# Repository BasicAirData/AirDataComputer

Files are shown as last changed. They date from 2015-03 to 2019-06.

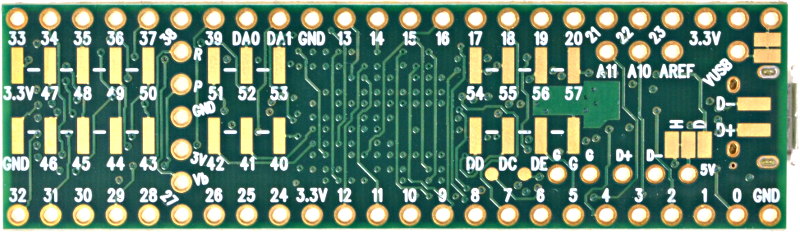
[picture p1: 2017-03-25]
Hardware/3D support/teensy3.6/images/teensy36 Back.jpg

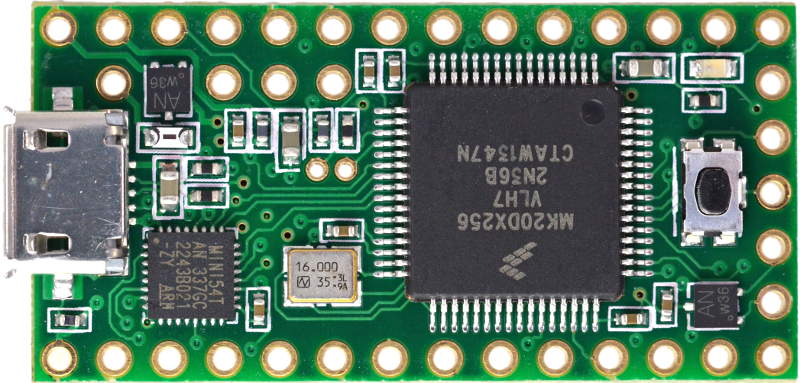
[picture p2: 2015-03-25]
Hardware/3D support/teensy3.1/images/teensy31front.jpg

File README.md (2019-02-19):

[Brainstorming in progress. New design. Rookies welcome](https://www.basicairdata.eu/projects/air-data-systems/brainstorming-air-data-system-winter-2018-2019/)

[Airborne ADC Video](http://www.basicairdata.eu/projects/skyeye/review-diy-air-data-computer-asgard-and-pitot-static-on-skyeye-rc-model/)
# [Air Data Computer](https://github.com/BasicAirData/AirDataComputer/wiki)
Asgard ADC

## Description
An air data computer (ADC) is an essential avionics component found in modern aircraft. This unit can determine True Airspeed, Mach number, Altitude, and common air properties from a pitot-static probe data and an outside air temperature probe.

This repository, together with the media published on the BasicAirData website, contains the information to build from scratch a recreational grade DIY Air Data Computer. This device can transmit data via USB serial port and Bluetooth, and log all data on a MicroSD.

The project is a work in progress

This Air Data Computer can be controlled sending plain text [messages](https://github.com/BasicAirData/AirDataComputer/tree/master/Software/Documentation/ADC%20Common%20Message%20Set) from any serial / bluetooth terminal.<br>
We are developing [Air Data Bridge](https://github.com/BasicAirData/AirDataBridge), a simple app for Android devices to connect via Bluetooth and use this ADC on-the-field in an easy way.

## At a Glance
* [Fast Assembly](https://www.basicairdata.eu/projects/airdatacomputer/asgard-adc/assembly-adc-asgard/)
* [Pictures](http://www.basicairdata.eu/projects/airdatacomputer/asgard-adc/adc-asgard-pictures/)
* [Typical applications](http://www.basicairdata.eu/projects/air-data-systems/air-data-systems-applications/)

## Reference documents

[Notes on firmware programming](https://www.basicairdata.eu/projects/notes-on-firmware-programming/)

[Basic Air Data Home Page](https://www.basicairdata.eu)

[Code of conduct](CODE_OF_CONDUCT.md)

[Contributing Information](CONTRIBUTING.md)

[Repository License](LICENSE)

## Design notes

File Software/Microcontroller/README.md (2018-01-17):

## Status
[Work in progress, refer to the Wiki](https://github.com/BasicAirData/AirDataComputer/wiki)

## Introduction
Within "Hardware Integration Test" folder you find a sketch for test the hardware of a Asgard ADC.
Firmware folder will contain the sketch that need to ve uploaded to ADC. The firmware supports Bluetooth and SD card.
Libraries folder contains the libraries you need to place in your Arduino IDE library folder to be able to compile the ADC sketch.

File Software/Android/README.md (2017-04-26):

## Asgard
Android Application to interface with the ADC

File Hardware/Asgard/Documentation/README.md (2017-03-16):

# Hardware Folder

In "Amaranthi2" folder you find all the Amaranth i2 ADC related material
* Enclosure	
* Kicad Amaranth i2	Printed Circuit Board
* Pinout	
* Schematic

In "3D support" folder you find free 3D models of the Teensy board 3.1/3.2 and the SD card holder used for the virtual assembly of Amaranth i2 ADC

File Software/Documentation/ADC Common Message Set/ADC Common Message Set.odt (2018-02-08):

BasicAirData – Air Data Computer

Communication Protocol - Common Message Set

Attention, this is a work in progress version

Draft Version 0.5 – 6th Feb 2018

Draft Version 0.4 – 6th Jan 2018

Draft Version 0.3 – 11th May 2017

Draft Version 0.2 – 26th Apr 2017

Draft Version 0.1 – 4th Jan 2017

Legend for the table colors:

- Green = implemented

- Red = not implemented

- Blue = work in progress

ID | Field | Field Name | Description
0 | HBQ | HEARTBEAT_REQ | Check if the system is present and responding
1 | HBA | HEARTBEAT_ASSERT | Answer about the system presence
2 | TMS | TIME_SET | Set date and time of the ADC
3 | TMQ | TIME_REQ | Ask for date and time
4 | TMA | TIME_ASSERT | The Date and time
5 | STS | STATUS_SET | Set the status
6 | STQ | STATUS_REQ | Ask for ADC configuration status
7 | STA | STATUS_ASSERT | The Status
8 | DTS | DATA_SET | Set the data
9 | DTQ | DATA_REQ | Ask for the ADC data
10 | DTA | DATA_ASSERT | The data
11 | LCS | LOG_CURRENTFILE_SET | Set the current log file name
12 | LCQ | LOG_CURRENTFILE_REQ | Ask for the current log file name
13 | LCA | LOG_CURRENTFILE_ASSERT | The current log file
14 | DFS | DATA_FREQ_SET | Set the ADC to send Data at specified frequencies
15 | DFQ | DATA_FREQ_REQ | Ask for the ADC Data Frequencies
16 | DFA | DATA_FREQ_ASSERT | The Data Frequencies
17 | FMQ | FILE_MANAGER_REQ | Manage SD Files
18 | FMA | FILE_MANAGER_ASSERT | File manager answers
19 | CCS | CALIBRATION_CON_SET | Setup Sensor Calibration
20 | CCA | CALIBRATION_CON_ASSERT | General calibration ack and parameter from ADC

Every message string will begin with a “$” character and will end with a “\n” (newline).

# 0 – HBQ – HEARTBEAT_REQ

The heartbeat message ask if a system is present and responding.

The remote system will respond with a HEARTBEAT_ASSERT (#1).

0 | Field String | $HBQ
1 | description | The description of the requesting device
2 | firmware_version | The version of the communication protocol

Example:

$HBQ,StatusVisualizer,1

# 1 – HBA – HEARTBEAT_ASSERT

The heartbeat message answer if a system is present and responding.

This message is typically the answer of a HEARTBEAT_REQ (#0).

0 | Field String | $HBA
1 | description | The description of the responding device
2 | firmware_version | The version of the communication protocol

Example:

$HBA,ASGARD,0.5

# 2 – TMS – TIME_SET

The request to set the remote datetime.

The remote system will respond with a TIME_ASSERT (#4).

0 | Field String | $TMS
1 | Time as seconds since Jan 1, 1970 | Long Integer, seconds

Example:

$TMS,1493151334

# 3 – TMQ – TIME_REQ

Ask for the remote datetime.

The remote system will respond with a TIME_ASSERT (#4).

0 | Field String | $TMQ

Example:

$TMQ

# 4 – TMA – TIME_ASSERT

The message contains the current datetime of the device.

0 | Field String | $TMA
1 | Time as seconds since Jan 1, 1970 | Long Integer, seconds

Example:

$TMA,1493151334

# 5 – STS – STATUS_SET

The request to set the status of the remote device.

It is possible to set some parameters and leave untouched some others, using the value “-1”.

The remote system will respond with a STATUS_ASSERT (#7).

0 | Field String | $STS
1 | SD card present | 1 Present. 0 Not present. E=error code
2 | Deltap sensor | 1 Present. 0 Not present. E=error code
3 | Absolute pressure sensor | 1 Present. 0 Not present. E=error code
4 | External Temperaure sensor | 1 Present. 0 Not present. E=error code
5 | Deltap sensor temperature | 1 Present. 0 Not present. E=error code
6 | Absolute pressure sensor temperature | 1 Present. 0 Not present. E=error code
7 | Real time clock battery | 1 Present. 0 Not present.
8 | Error/Warning | That should be a code handled directly by firmware. Exception handling is not implemented. “SDLOW” This is a warning
9 | BT Present | 1 Present. 0 Not present. E=error code (BT module hooked to Serial1)

Example:

$STS,1,1,-1,1,1,1,1,N,1

# 6 – STQ – STATUS_REQ

Ask for the remote status.

The remote system will respond with a STATUS_ASSERT (#7).

0 | Field String | $STQ

Example:

$STQ

# 7 – STA – STATUS_ASSERT

The message contains the current status of the device.

0 | Field String | $STA
1 | SD card present | 1 Present. 0 Not present. E=error code. N not set.
2 | Deltap sensor | 1 Present. 0 Not present. E=error code. N not set.
3 | Absolute pressure sensor | 1 Present. 0 Not present. E=error code. N not set.
4 | External Temperaure sensor | 1 Present. 0 Not present. E=error code. N not set.
5 | Deltap sensor temperature | 1 Present. 0 Not present. E=error code. N not set.
6 | Absolute pressure sensor temperature | 1 Present. 0 Not present. E=error code
7 | Real time clock battery | 1 Present. 0 Not present.
8 | Error/Warning | That should be a code handled directly by firmware. Exception handling is not implemented. “SDLOW” This is a warning
9 | BT Present | 1 Present. 0 Not present. E=error code (BT module hooked to Serial1)

Example:

$STA,1,1,1,1,1,1,1,,0

All the sensors, SD card, real time clock battery are present and operational, no errors are reported.

$STA,1,1,0,1,1,1,0,SDLOW,1

All the sensors except external temperature, and SD card are present. SD card space shortage is reported.

# 8 – DTS – DATA_SET

The request to set (force) the data of the remote device.

It is possible to set some parameters and leave untouched some others, using the value “-1”.

The remote system will respond with a DATA_ASSERT (#10). [Note. How to decide what #10 message should include? The reply #10 will contain no data at all “$DTA”. It’ a simple acknowledge]

i | Field String | $DTA
1 | Timestamp see msg #4 | Time as seconds since Jan 1, 1970
2 | Deltap [Sensor units, counts] | integer. Sensor dependent.
3 | Absolute Pressure [Sensor units, counts] | integer. Sensor dependent
4 | Ext Temperature [Sensor units, counts] | integer. Sensor dependent
5 | Temp deltap [Sensor units, counts] | integer. Sensor dependent
6 | Temp absolute [Sensor units, counts] | integer. Sensor dependent
7 | Deltap [Pa] | float
8 | Absolute Pressure [Pa] | float
9 | Ext Temperature [K] | float
10 | Temp deltap [K] | float
11 | Temp absolute [K] | float
12 | IAS [m/s] | float
13 | TAS [m/s] | float
14 | Altitude [m] | float
15 | OAT [K] | float
16 | Relative time micro millis [s*10^-6] | integer
17 | Uncertainty IAS [m/s] | float
18 | Uncertainty TAS [m/s] | float
19 | Uncertainty Altitude [m] | float
20 | Uncertainty OAT [K] | float
21 | Air Density [kg/m^3] | float
22 | Air Viscosity [Pa*s] | float
23 | Re | float
24 | c factor | float

Example:

Set the value of ext temperature

$DTS,,,,,,,,,350,,,,,,,,,,,,,,,

# 9 – DTQ – DATA_REQ

Ask for the remote data. Selects the required data with the fields value. If a 0 is sent at the position i then the ADC will send a #10 reply with the field i not valued. If a 1 is sent at the position i then the ADC will send a #10 reply with the field i valued.

Configuration data will be saved to the SD card (CONFIG.CFG file),

Use the “$DTQ” command, without parameters, and the remote system will respond with a DATA_ASSERT (#10) instead.

i | Field String | $DTQ
1-24 | Select | 0 if data field not required. 1 if data field required

Example:

Request all the data fields of #10

$DTQ,1,1,1,1,1,1,1,1,1,1,1,1,1,1,1,1,1,1,1,1,1,1,1,1

Request all the data fields except Deltap and Ext Temperature

$DTQ,1,0,1,0,1,1,1,1,1,1,1,1,1,1,1,1,1,1,1,1,1,1,1,1

Request time, deltap, p, ext temperature

$DTQ,1,0,0,0,0,0,1,1,1,0,0,0,0,0,0,0,0,0,0,0,0,0,0,0

Simply request a string of data

$DTQ

# 10 – DTA – DATA_ASSERT

Data lengths shown in the table below are variable and conservative. The ADC will respond to a #9 message with a DTA – DATA_ASSERT that contains only the data fields that have been marked with 1 within the #9 message.

i | Field String | $DTA
1 | Timestamp see msg #4 | Time as seconds since Jan 1, 1970
2 | Deltap [Sensor units, counts] | 6 Chars, integer. Sensor dependent.
3 | Absolute Pressure [Sensor units, counts] | 6 Chars, integer. Sensor dependent
4 | Ext Temperature [Sensor units, counts] | 5 Chars, integer. Sensor dependent
5 | Temp deltap [Sensor units, counts] | 5 Chars, integer. Sensor dependent
6 | Temp absolute [Sensor units, counts] | 5 Chars, integer. Sensor dependent
7 | Deltap [Pa] | 8 Chars, 2 decimal digit
8 | Absolute Pressure [Pa] | 8 Chars, 1 decimal digit
9 | Ext Temperature [K] | 5 Chars, 1 decimal digit
10 | Temp deltap [K] | 5 Chars, 1 decimal digit
11 | Temp absolute [K] | 5 Chars, 1 decimal digit
12 | IAS [m/s] | 6 Chars, 2 decimal digit
13 | TAS [m/s] | 6 Chars, 2 decimal digit
14 | Altitude [m] | 7 Chars, 2 decimal digit
15 | OAT [K] | 5 Chars, 1 decimal digit
16 | Relative time micro millis [s*10^-6] | 5 Chars, integer
17 | Uncertainty IAS [m/s] | 3 Chars, 1 decimal digit
18 | Uncertainty TAS [m/s] | 3 Chars, 1 decimal digit
19 | Uncertainty Altitude [m] | 3 Chars, 1 decimal digit
20 | Uncertainty OAT [K] | 3 Chars, 1 decimal digit
21 | Air Density [kg/m^3] | 8 Chars, 6 decimal digit
22 | Air Viscosity [Pa*s] | 10 Chars, 8 decimal digit
23 | Re | 8 Chars, 1 decimal digit
24 | c factor | 6 Chars, 4 decimal digit

Example:

$DTA,1493151334,6608,******,******,*****,*****,*****,472.60,100926.1,15.0,18.3,18.6,27.77,27.77,63.1,15.0,1244,0.4,0.7,1.1,0.3,1.225000,18.396057,15081.1,0.9977

# 11 – LCS – LOG_CURRENTFILE_SET

This message request to set the current active log file name. Reply is #13 msg.

If the file doesn’t exist, a new file is created.

0 | Field String | $LCS
1 | Name | The requested log file name. Use the “?” character to create a new one using a progressive number

Example: (set the file to DATALOG.CSV)

$LCS,DATALOG.CSV

Example: (set the file to a new file. a progressive name, starting from LOG_0000.CSV, will be assigned)

$LCS,LOG_?.CSV

# 12 – LCQ – LOG_CURRENTFILE_REQ

Ask for the log file name. Reply is the active file name message #13

0 | Field String | $LCQ

Example:

$LCQ

# 13 – LCA – LOG_CURRENTFILE_ASSERT

The message contains the current active log file.

0 | Field String | $LCA
1 | frequency | The current active log file name

Example:

$LCA,DATALOG.CSV

# 14 – DFS – DATA_FREQ_SET

The request to set the frequency rate of the remote data messages.

It is possible to set some parameters and leave untouched some others, using the value “-1”.

The remote system will respond with a DATA_FREQ_ASSERT (#16).

0 | Field String | $DFS
1 | COM frequency | The requested frequency rate (messages per second) to Serial interface
2 | BT frequency | The requested frequency rate (messages per second) to Bluetooth
3 | SD frequency | The requested frequency rate (messages per second) to SD Card

Example: (set the serial frequency to 10 Hz, Bluetooth frequency to 0.5 Hz, and SD frequency to 30 Hz)

$DFS,10,0.5,30

Example: (set the Bluetooth frequency to 2 Hz. SD and Serial frequency won’t be changed)

$DFS,-1,2,-1

# 15 – DFQ – DATA_FREQ_REQ

Query the frequency rate of the remote data messages.

The remote system will respond with a DATA_FREQ_ASSERT (#16).

0 | Field String | $DFQ

Example:

$DFQ

# 16 – DFA – DATA_FREQ_ASSERT

The message contains the current frequency rate of the data messages.

0 | Field String | $DFA
1 | COM frequency | The current frequency rate (messages per second) to Serial
2 | BT frequency | The current frequency rate (messages per second) to Bluetooth
3 | SD frequency | The current frequency rate (messages per second) to SD Card

Example: (A serial frequency of 10 Hz, Bluetooth frequency of 1 Hz, and SD frequency of 30 Hz)

$DFA,10,1,30

# 17 – FMQ – FILE_MANAGER_REQ

Manage Log Files on SD card.

0 | Field String | $FMQ
1 | Command | LST = FILE_LIST NEW = NEW_FILE DEL = DELETE_FILE PRP = FILE_PROPERTIES DMP = FILE_DUMP
2 | Operation parameter | Filename, if file list is selected is left void

Example: (Get the list of file currently on the SD root directory)

FMQ,LST

Example: (Creates the file LOG1.CSV)

FMQ,NEW,LOG1.CSV

Example: (Deletes the file LOG1.CSV)

FMQ,DEL,LOG1.CSV

Example: (Gets LOG1.CSV file properties)

FMQ,PRP,LOG1.CSV

Example: (Dumps PAGNOTTA.CSV file content)

FMQ,DMP,PAGNOTTA.CSV

# 18 – FMA – FILE_MANAGER_ASSERT

Data from SD files. Payload depends on #17 FMQ Message

In reply to msg #17 FILE_LIST = LST

Number of total parameters equal to 3n+2, n is the number of files present on the SD card.

0 | Field String | $FMA
1 | Command | LST
2 | Number of files | Integer, the number of transmitted files
3 | Field2 | Filename #1
4 | Field3 | Size file #1
5 | Field4 | Timestamp #1; Time as seconds since Jan 1, 1970 (Long Integer)
6 | Field5 | Filename #2
7 | Field6 | Size file #2
… | … | …
3n+2 | Field(3n+2) | Timestamp #n; Time as seconds since Jan 1, 1970 (Long Integer)

Example: (The root directory contains 3 files)

$LFA,LST,3,DATALOG.CSV,1560,1517256700,LOG1.CSV,0,1517251200,PAGNOTTA.CSV,68203,1517256745

In reply to msg #17 NEW_FILE = NEW

Acknowledge the creation of a new file. The new file is set as current ADC log file.

0 | Field String | $FMA
1 | Command | NEW
2 | File name | The name of the newly created file Use the “?” character to create a new one using a progressive number

Example:

$FMA,NEW,PAGNOTTA.CSV (PAGNOTTA.CSV created)

Example:

$FMA,NEW,LOG_?.CSV (if LOG_0000.CSV exists, LOG_0001.CSV created)

In reply to msg #17 DEL_FILE = DEL

Acknowledge the deletion of specified file.

0 | Field String | $FMA
1 | Command | DEL
2 | File name | The name of the file

Example:

$FMA,DEL,PAGNOTTA.CSV (PAGNOTTA.CSV deleted)

$FMA,DEL (No files deleted)

In reply to msg #17 FILE_PROPERTIES = PRP

Returns the name and the dimension of the specified file.

0 | Field String | $LFA
1 | Command | PRP
2 | Name | The name of the file
3 | Size | Size in bytes of specified file
4 | Timestamp | Time as seconds since Jan 1, 1970 (Long Integer)

Example:

$FMA,PRP,PAGNOTTA.CSV,15600,1517256700 (returns PAGNOTTA.CSV properties)

$FMA,PRP (returns nothing)

In reply to msg #17 FILE_DUMP = DMP

Returns the log file contents line by line.

Another message received by the same serial interface will stop the dump truncating the file

Message is always ended with a special $EOF sequence.

In order, it returns:

1) The $FMA string:

0 | Field String | $FMA
1 | Command | DMP
2 | Name | The name of the file

2) The file content:

First line

Second line

…. (Send another message to stop this phase and truncate the file)

Last line

3) The End of File acknowledgment

$EOF

Example: (it dumps PAGNOTTA.CSV file)

$FMA,DMP,PAGNOTTA.CSV

$DTA,first_line

$DTA,last_line

$EOF

# 19 –CCS–CALIBRATION_CON_SET

Manages calibration parameter of sensors.

General command message structure

0 | Field String | $CCS
1 | Command | EXE – Order to perform a calibration on the specified sensor and with the mode specified USE – Applies the specified calibration parameters to the sensor SEN – Send out the calibration data for the specified sensor
2 | Sensor_ID_number | The ID number of the sensorr
3 | Mode | 1 – Offset Only 2 - Linear
4 | Parameter 1 | Command dependent
5 | Parameter 2 | Command dependent

EXE – Command description

After a EXE command is issued the ADC performs the required calibration routine on the sensors and update the required sensor information. After the procedure is complete the ADC sent out a message #20 CCQ.

0 | Field String | $CCS
1 | Command | EXE
2 | Sensor_ID_number | The ID number of the sensor. Integer, 2 Bytes
3 | Mode | 1 – Offset Only, calibrate the indicated sensor zero offset 2 – Linear, calibrate the indicated sensor zero offset and gain

EXAMPLE:

$CCS,EXE,1,1

Once finished sent out a message #20 containing the offset parameter used

USE – Command description

The ADC uses the specified calibration information and reply with a #20 message.

0 | Field String | $CCS
1 | Command | USE
2 | Sensor_ID_number | The ID number of the sensor. Integer, 2 Bytes
3 | Mode | 1 – Offset Only, calibrate the indicated sensor zero offset 2 – Linear, calibrate the indicated sensor zero offset and gain
4 | Parameter 1 | Offset if Mode==1
5 | Parameter 2 | Gain if Mode==2

EXAMPLE:

$CCS,USE,2,1,45,,

The ADC sets the sensor 2 offset to 45, then send out a #20 message $CGQ,2,45,,

SEN – Command description

Send out the calibration data for the specified sensor. Returns calibration offset and gain

0 | Field String | $CCS
1 | Command | SEN
2 | Sensor_ID_number | The ID number of the sensorr

Example:

$CCS,SEN,1

Reply

$CCA,1,1234,0.995955

HWD– Command description

The ADC uses the specified sensor hardware information and reply with a #20 message that contains all the data fields.

0 | Field String | $CCS
1 | Command | HWD
2 | Deltap Sensor Min Count value | Minimum number of counts read by the deltap sensor
3 | Absolute pressure sensor Min Count value | Minimum number of counts read by the abs pressure sensor
4 | Deltap Sensor Max Count value | Maximum number of counts read by the deltap sensor
5 | Absolute pressure sensor Max Count value | Maximum number of counts read by the abs pressure sensor
6 | Deltap Sensor Min Pressure | Minimum pressure deltap sensor. Pascal
7 | Abs Sensor Min Pressure | Minimum pressure abs sensor. Pascal
8 | Deltap Sensor Max Pressure | Maximum pressure deltap sensor. Pascal
9 | Abs Sensor Max Pressure | Maximum pressure abs sensor. Pascal

# 20 –CALIBRATION_CON_ASSERT

Reply to message #19, EXE Command

Reply to #19 message . Command EXE mode 1. The reply will be the same of that required to a message #19, Command SEN mode 1 or Message #19, Command USE mode 1

0 | Field String | $CCA
1 | Sensor_ID_number | The ID number of the sensor. Integer, 2 Bytes
2 | Parameter 1 | Offset value. Integer, 6 bytes

EXAMPLE:

In reply to #19 $CCS,EXE,1,1

$CCA,1,25

The #20 reply contents the used offset value 25 for the sensor 1

Reply to message #19, USE Command

Reply to #19 message . Command USE mode 2, Command SEN mode 2

0 | Field String | $CCA
1 | Sensor_ID_number | The ID number of the sensor. Integer, 2 Bytes
2 | Parameter 1 | Offset value. Integer, 6 bytes
3 | Parameter 2 | Gain

EXAMPLE:

In reply to #19 $CCS,USE,1,2

$CCA,1,25.0.99995

The #20 reply contents the used offset value 25 and the gain 0,99995 for the sensor 1

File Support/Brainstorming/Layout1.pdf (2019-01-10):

Analog pressure
sensors
5V
6 Channels

Integrated data acquisition System

Nos. 3 to 5 ELVR Dp
1” (https://eu.mouser.com/ProductDetail/Amphenol-All-Sensors/ELVR-L01D-F1RT-I-NA5F) and 10” (https://eu.mouser.com/ProductDetail/Amphenol-All-Sensors/ELVR-L10D-F1RT-I-NA5F) in H2O range
pressure sensors
N.1
BARO-A-4V-MINI-PRIME (https://eu.mouser.com/ProductDetail/All-Sensors/BARO-A-4V-MINI-PRIME?qs=ILks%2FQglqVSxsY2LQVPGvQ%3D%3D)

Nos. 1
ADAS3022BSTZ : 16-Bit, 1
MSPS, 8-Channels (https://eu.mouser.com/ProductDetail/Analog-Devices/ADAS3022BSTZ)
SPI
BUS

Host Microcontroller board Teensy 3.6

Proposal, components to be used for the new unit

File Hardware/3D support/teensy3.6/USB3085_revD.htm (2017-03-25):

Rapporto di conversione di Autodesk Inventor | mercoledì 23 aprile 2014 (15:11)

File di origine: | C:\Users\larraguetajunior\Dropbox\UAV\AIRDATACOMPUTER\commerciali\USB3085_revD.step
Tipo programma di conversione: | STEP | Sistema di invio: | SolidWorks 2010
Autore: | | Durata conversione: | 00:00:01

Opzioni
Tipo importazione: | N/A
Tipi di entità da importare: | Solidi, Superfici, Wire, Punti
Importa in ambiente di correzione: | Sì
Importa assieme come parte singola: | No
Crea superfici come: | Lavorazione a composto singolo
Unità:
Controlla parti al caricamento: | No
Unione automatica: | No
Abilita correzione avanzata: | N/A

## Componenti

La tabella seguente elenca le parti e gli assiemi creati in Inventor:

+/- | Nome | File di Inventor | Stato
[ ] | USB3085_revD.iam | C:\Users\larraguetajunior\Dropbox\UAV\AIRDATACOMPUTER\commerciali\Imported Components\USB3085_revD\USB3085_revD.iam | Riuscito
[ ] | MICRO-USB-AB-SMT-SHELL.ipt | C:\Users\larraguetajunior\Dropbox\UAV\AIRDATACOMPUTER\commerciali\Imported Components\USB3085_revD\MICRO-USB-AB-SMT-SHELL.ipt | Riuscito
[+] [-] | MICRO-USB-AB-HOUSING.ipt | C:\Users\larraguetajunior\Dropbox\UAV\AIRDATACOMPUTER\commerciali\Imported Components\USB3085_revD\MICRO-USB-AB-HOUSING.ipt | Sconosciuto

Gravità | ID entità | Messaggio
Sconosciuto | 11293 | Alcune superfici sono state semplificate

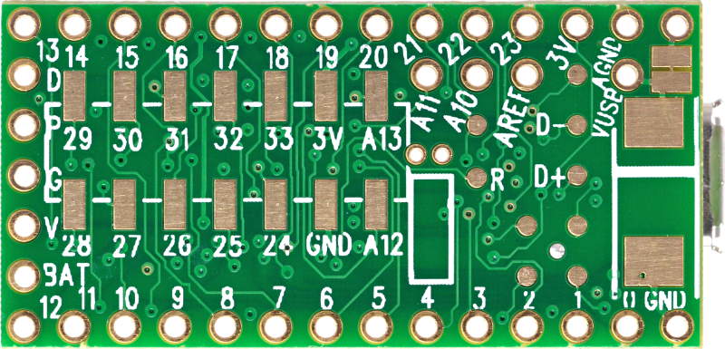
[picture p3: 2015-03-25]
Hardware/3D support/teensy3.1/images/teensy31back.jpg

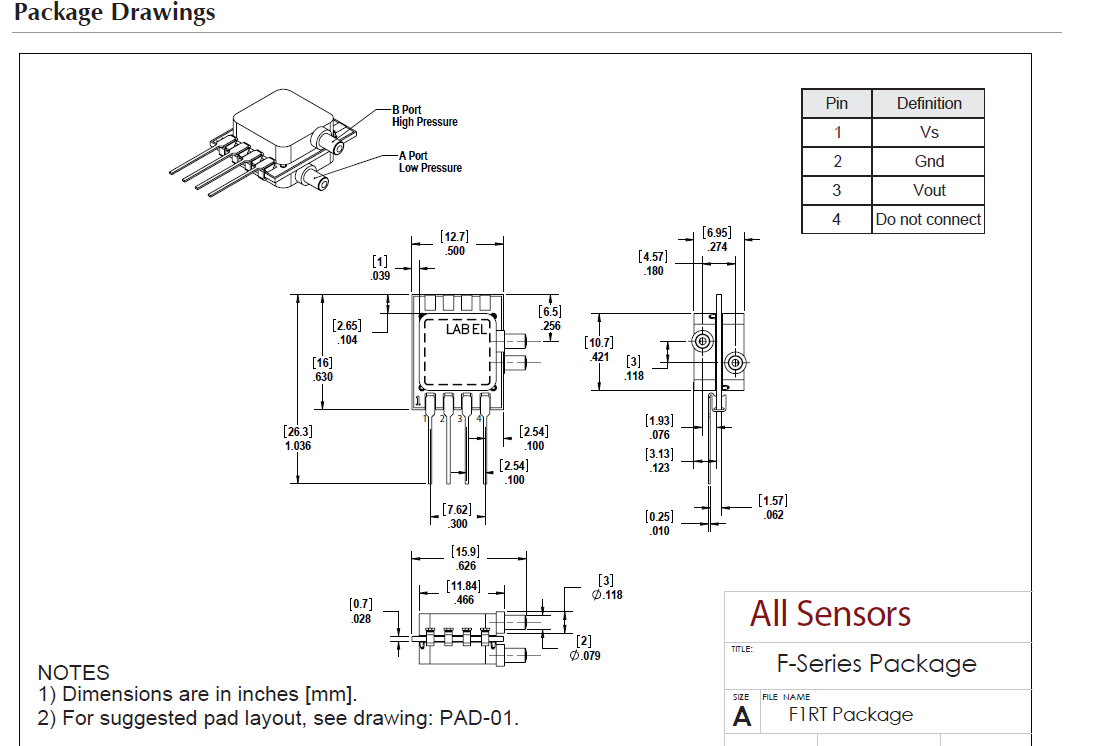
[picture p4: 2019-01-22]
Hardware/kicad4ADSb0.1/ADSSBb0.1/Pictures/pinoutpressure.png

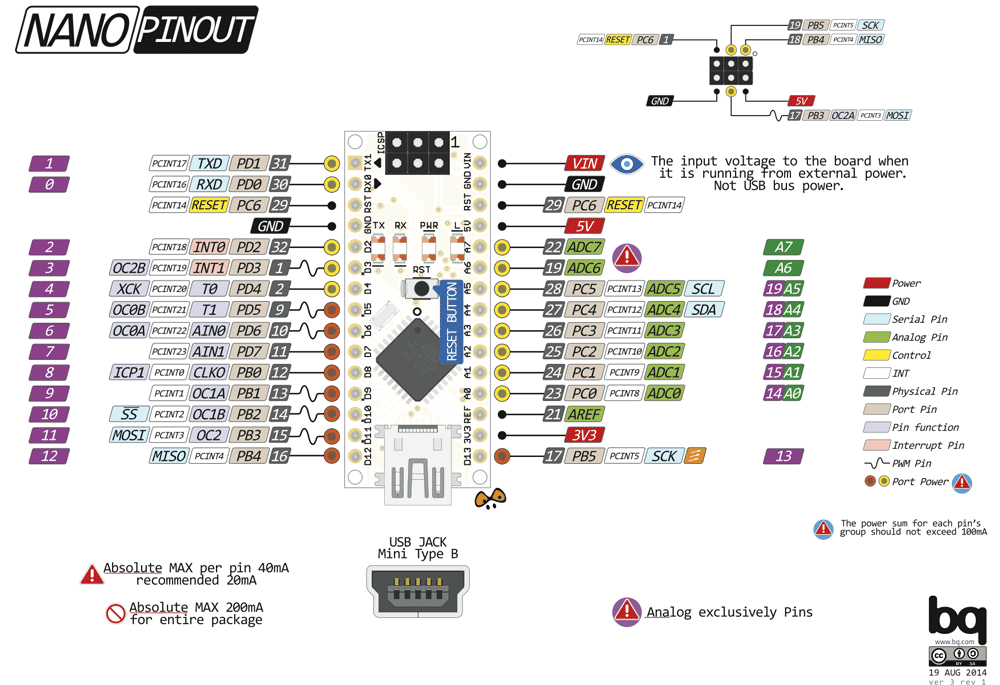
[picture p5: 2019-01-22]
Hardware/kicad4ADSb0.1/ADSSBb0.1/Pictures/pinout.png

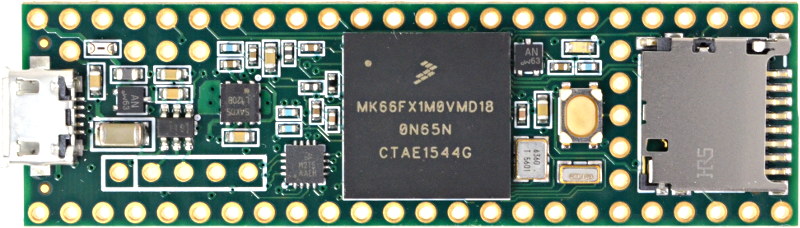
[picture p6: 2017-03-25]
Hardware/3D support/teensy3.6/images/teensy36. frontjpg.jpg

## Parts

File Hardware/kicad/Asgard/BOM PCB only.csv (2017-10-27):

Quantity | MPN | Designator | Footprint | Comment | Description
2 | 855-D01-9973242 | ABS, DELTAP | SIL 4 | Straight female Socket | 4-pin through-hole connector
1 | 517-974-01-04-RK | BLUETOOTH | 4x2.54 Pitch | Straight female Socket | 4-pin through-hole connector
2 | 517-929850-01-24-RA | TEENSY USB SIDE | 24x2.54 Pitch | Straight female Socket | 24-pin through-hole connector
4 | 603-CFR-25JT-52-1K | R1, R2, R3, R4 | Through-hole connector | Vertical mounted resistor | 1/8 W vertical mounted resistor

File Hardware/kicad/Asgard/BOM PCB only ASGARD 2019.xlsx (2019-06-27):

Designator | Manufacturer Part Number or Seeed SKU | Qty | Link
ABS, DELTAP | 855-D01-9973242 | 2 | https://www.mouser.it/ProductDetail/Harwin/D01-9973242?qs=ecHgFjcWJS%252BVNM5C80XwDA%3D%3D
BLUETOOTH | 517-974-01-04-RK | 1 | https://www.mouser.it/ProductDetail/3M-Electronic-Solutions-Division/929974-01-04-RK
TEENSY USB SIDE | 517-929850-01-24-RA | 2 | https://www.mouser.it/ProductDetail/3M-Electronic-Solutions-Division/929850-01-24-RA
R1, R2, R3, R4 | 299-4.7K-RC | 4 | https://www.mouser.it/ProductDetail/Xicon/299-47K-RC

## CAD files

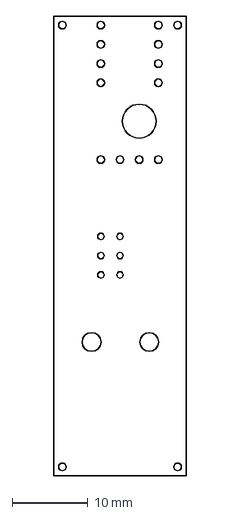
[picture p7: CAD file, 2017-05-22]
Hardware/kicad/FromCAD/PCBLayout.dxf
17.6 x 60.8 mm

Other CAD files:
Hardware/3D support/MICRO SD ADAPTER/OldVersions/5031821852MICROSDADAPTER.0005.ipt
Hardware/3D support/MICRO SD ADAPTER/microsdadapterboard.ipt
Hardware/3D support/MICRO SD ADAPTER/pinSDCARDTOTEENSY.ipt
Hardware/3D support/teensy3.1/MiniUSB.ipt
Hardware/3D support/teensy3.1/Teensy3.1.iam
Hardware/3D support/teensy3.1/Teensyboard.ipt
Hardware/3D support/teensy3.6/24 Pin Straight Header.iam
Hardware/3D support/teensy3.6/5031821852MICROSDADAPTER.ipt
Hardware/3D support/teensy3.6/MICRO-USB-AB-HOUSING.ipt
Hardware/3D support/teensy3.6/MICRO-USB-AB-SMT-SHELL.ipt
Hardware/3D support/teensy3.6/MiniUSB.ipt
Hardware/3D support/teensy3.6/Pin Stopper 0.6mm.ipt
Hardware/3D support/teensy3.6/Single Header Pin.iam
Hardware/3D support/teensy3.6/Straight Header Pin.ipt
Hardware/3D support/teensy3.6/Teensy3.6withheaders.iam
Hardware/3D support/teensy3.6/Teensyboard.ipt
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

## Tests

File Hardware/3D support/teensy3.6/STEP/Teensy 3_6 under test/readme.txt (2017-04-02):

Downloaded from forum
https://forum.pjrc.com/threads/41007-3D-Cad-for-Teensy-3-5-and-3-6?p=138798&viewfull=1#post138798
Released by @ZS6HG

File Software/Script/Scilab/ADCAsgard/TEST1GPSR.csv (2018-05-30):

type | time | latitude | longitude | accuracy (m) | altitude (m) | geoid_height (m) | speed (m/s) | bearing (deg) | sat_used | sat_inview | name | desc
T | 2018-05-27 08:59:00 | 37.235 | -115.811111 | 3 | 58.749 | 40.251 | 0 |  | 22 | 23 | 20180527-105900 | GPS Logger: 20180527-105900
T | 2018-05-27 09:00:50 | 37.23495451 | -115.81058984 | 3 | 60.749 | 40.251 | 0 |  | 22 | 23
T | 2018-05-27 09:00:51 | 37.23495557 | -115.8105903 | 3 | 60.749 | 40.251 | 0 |  | 22 | 23
T | 2018-05-27 09:00:52 | 37.2349559 | -115.81059307 | 3 | 60.749 | 40.251 | 0 |  | 22 | 23
T | 2018-05-27 09:00:53 | 37.2349559 | -115.81059307 | 4 | 60.749 | 40.251 | 0 |  | 22 | 23
T | 2018-05-27 09:00:54 | 37.2349537 | -115.81059313 | 3 | 60.749 | 40.251 | 0.25 | 56 | 22 | 23
T | 2018-05-27 09:00:55 | 37.23495191 | -115.81059376 | 4 | 60.749 | 40.251 | 0.25 | 56 | 22 | 23
T | 2018-05-27 09:00:56 | 37.23492052 | -115.81057695 | 4 | 60.749 | 40.251 | 1.75 | 161 | 22 | 23
T | 2018-05-27 09:00:57 | 37.23490579 | -115.81056969 | 6 | 60.75 | 40.25 | 1.75 | 161 | 22 | 23
T | 2018-05-27 09:00:58 | 37.23484782 | -115.81054231 | 7 | 61.75 | 40.25 | 3.75 | 161 | 22 | 23
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

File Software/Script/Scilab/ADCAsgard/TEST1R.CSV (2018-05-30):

$DTA | 1527410688 | 8179 | 9947 | 259 | 927 | 912 | 12.79 | 101437.5 | 306.6 | 313.7 | 312.3 | 4.57 | 4.71 | -9.36 | 306.6 | 1304907 | 0.9 | 0.9 | 0.4 | 0.2 | 1.152824 | 0.00001854 | 2343.8 | 1.0004
$DTA | 1527410688 | 8173 | 9944 | 259 | 927 | 912 | 19.19 | 101400.9 | 306.6 | 313.7 | 312.3 | 5.60 | 5.77 | -6.31 | 306.6 | 1304927 | 0.7 | 0.8 | 0.4 | 0.2 | 1.152407 | 0.00001854 | 2869.8 | 1.0003
$DTA | 1527410688 | 8176 | 9947 | 259 | 927 | 912 | 15.99 | 101437.5 | 306.6 | 313.7 | 312.3 | 5.11 | 5.27 | -9.36 | 306.6 | 1304947 | 0.8 | 0.8 | 0.4 | 0.2 | 1.152824 | 0.00001854 | 2620.3 | 1.0003
$DTA | 1527410688 | 8173 | 9947 | 259 | 927 | 912 | 19.19 | 101437.5 | 306.6 | 313.7 | 312.3 | 5.60 | 5.77 | -9.36 | 306.6 | 1304967 | 0.7 | 0.8 | 0.4 | 0.2 | 1.152824 | 0.00001854 | 2870.3 | 1.0003
$DTA | 1527410688 | 8170 | 9944 | 257 | 927 | 912 | 22.38 | 101400.9 | 306.0 | 313.7 | 312.3 | 6.05 | 6.23 | -6.31 | 306.0 | 1304987 | 0.7 | 0.7 | 0.4 | 0.2 | 1.154841 | 0.00001853 | 3104.7 | 1.0003
$DTA | 1527410688 | 8184 | 9947 | 258 | 927 | 912 | 7.46 | 101437.5 | 306.3 | 313.7 | 312.3 | 3.49 | 3.60 | -9.36 | 306.3 | 1305007 | 1.2 | 1.2 | 0.4 | 0.2 | 1.154040 | 0.00001854 | 1791.8 | 1.0005
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

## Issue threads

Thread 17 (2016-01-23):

Wrong printout of temperature and air data

JLJu, 2016-01-23:
Chekout the datalog printout. Negative density can be a problem :-)
$TEX,Rho[kg/m^3],_TAT[K],_TAT[C],_uTAT[K;C],_p[Pa],Viscosity[Pas1e-6],hour,minute,second,month,day,year,millis
$TEX,-1.268252,-273.21,-546.36,0.50,101325.00,46.007809,22,15,10,1,21,2016,1804640
$TEX,1.291896,273.40,0.25,0.50,101325.00,17.930244,22,30,10,1,21,2016,2704645
$TEX,-1.267697,-273.33,-546.48,0.50,101325.00,45.991993,22,45,10,1,21,2016,3604650
$TEX,1.291612,273.46,0.31,0.50,101325.00,17.931444,23,0,10,1,21,2016,4504655
$TEX,-1.268252,-273.21,-546.36,0.50,101325.00,46.007809,23,15,10,1,21,2016,5404660
$TEX,-1.267975,-273.27,-546.42,0.50,101325.00,45.999897,23,30,10,1,21,2016,6304667
$TEX,-1.264516,-274.02,-547.17,0.50,101325.00,45.901535,23,45,10,1,21,2016,7204673
$TEX,-1.263643,-274.21,-547.36,0.50,101325.00,45.876766,0,0,10,1,22,2016,8104679
$TEX,-1.261946,-274.58,-547.73,0.50,101325.00,45.828712,0,15,10,1,22,2016,9004685
$TEX,-1.260482,-274.90,-548.05,0.50,101325.00,45.787338,0,30,10,1,22,2016,9904691
$TEX,-1.262496,-274.46,-547.61,0.50,101325.00,45.844273,0,45,10,1,22,2016,10804697

Closed 2016-08-03.

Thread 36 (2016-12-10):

Define, document and reference the method to calculate flowrate in HVAC applications

JLJu, 2016-12-10:
Expose the whole numeric method and produce a working example
Revise and expand this material
http://basicairdata.blogspot.it/2015/11/flow-rate-in-circular-pipe.html

Basic Air Data note. An article request has been put into the articles pitch queue.

Closed 2018-01-12.

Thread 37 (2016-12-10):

Insert the Temperature Logger Application into the library examples

JLJu, 2016-12-10:
Create an example folder and insert the [temperature logger application](http://www.basicairdata.eu/projects/airdatacomputer/library-use-case-sd-enabled-temperature-logger/).

Closed 2017-03-16.

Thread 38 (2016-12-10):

Documentation - ADC Library-

JLJu, 2016-12-10:
Write a detailed description of library functionalities. Actually, that information is spread out within the code and different documentation. A fresh start will be lovely.

JLJu, 2017-03-15:
From now on library doc will be produced with Doxygen.
[Documentation](https://github.com/BasicAirData/AirDataComputer/wiki/Documentation)
When we will arrive at a new stable release we will consider to add some tutorial like material.

Closed 2017-03-15.

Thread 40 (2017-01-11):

Convert ADC enclosure drawing files to convenient open standard

JLJu, 2017-01-11:
All our files should be freely usable and editable. Right now the [ADC enclosure drawings](http://www.basicairdata.eu/projects/airdatacomputer/amaranth-i2-assembly-tutorial/) are not in an editable format. [Freecad](www.freecadweb.org) format can do the job, we need a conversion to a free editor format.

Closed 2018-01-12.

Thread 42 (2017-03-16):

Revision of ADC Communication protocol

JLJu, 2017-03-16:
Under the point of view of bandwidth a "Monolithic" approach to data exchange can be a problem over a wireless link, if required sample rate is high.
Check message number 10 within Rev 1
[WIP ADC DOC](https://github.com/BasicAirData/AirDataComputer/blob/master/Software/Documentation/Work%20in%20progress%20ADC%20Common%20Message%20Set.odt)
I think is better instead to give the possibility to the user to receive subsets of data. In such a way it will be possible to arrange for limited bandwidth situations, low power requirements, and fast sample rate.

GrazianoCapelli, 2017-03-16:
A couple of notes/proposal about the $DTA message:

1) In case, could we consider to move the timestamp in the first fields? Timestamp is fundamental and present in any set of data, and it is the first check to do in order to find duplicates and, in case, reorder data. Useful in case of communication interruption;

2) The message could remain the same also in case you want to receive a subset of data: we could simply send the message sending commas without put any values between them. Could be a good start to limit bandwidth without introduce any complication. The $DTQ request could contain a series of 1 and 0, depending on data fields you requires.

JLJu, 2017-03-16:
1. Ok.
2. Yes, the simpler the better. Vector mask ok :-)

JLJu, 2017-03-16:
File updated [ADC DOC](https://github.com/BasicAirData/AirDataComputer/blob/master/Software/Documentation/Work%20in%20progress%20ADC%20Common%20Message%20Set.odtt)

Closed 2017-04-28.

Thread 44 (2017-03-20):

Requirements and Features

JLJu, 2017-03-20:
Here you can post your requirements for the Air Data Computer.

JLJu, 2017-04-28:
It makes more sense to open an issue on purpose :-)

JLJu, 2017-12-04:
Time to start to think about [ADC Asgard](https://github.com/BasicAirData/AirDataComputer/wiki/Requirements) enhancements. We will be working on a new [air data boom](https://github.com/BasicAirData/AirDataBoom), full DIYers compatible construction in carbon fiber and 3D printed parts, so it would be nice to update the ADC with the necessary software to handle an angle of attack vane /Angle of sideslip. Hardware should be already able to carry on this task without substantial modifications.

Closed 2018-01-17.

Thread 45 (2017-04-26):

Make a simple android app to test ADC communication via Bluetooth

GrazianoCapelli, 2017-04-26:
I propose to make a first android app (a simple **ADC Tester**), in order to:
- Verify and test the ADC communication protocol;
- Find possible bottlenecks and limits of the Bluetooth interface;
- Refine protocol, transmission methods, and connection setup in order to optimize the system;
- Find the best way to implement the communication on Android-side;
- (Last but not least) Give to all users a fast and simple way to test their own DIY units;

JLJu, 2017-04-26:
That will be great! Not to say that this will be the first fully-fledged plug and play DIY solution :-). Of course, consider me on board. I can help with Android Apps.
The basic test of libraries is proceeding and will end soon. Update of documentation is next to completion.

GrazianoCapelli, 2017-05-05:
A small app has been committed (commit a30a686) in order to offer a fast way to test the device via Bluetooth. The app can connect / disconnect, send and receive messages, and presents the messages in a Terminal-like way.
This is obviously a first start point, it needs some (many) adjustments and refinements.

JLJu, 2017-05-09:
A screen shot of ADCTester communicating with the ADC. By far the best! :-)
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

Closed 2017-07-23.

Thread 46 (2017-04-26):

ADC Common Message Set

JLJu, 2017-04-26:
Referring to the [ADC Common Message Set](https://github.com/BasicAirData/AirDataComputer/blob/master/Software/Asgard/Documentation/Work%20in%20progress%20ADC%20Common%20Message%20Set.odt) implementation.
Message No.19	LGA	LOG_FILE_ASSERT
This message is supposed to retrieve a specific line of the log file. I'm lost about the possible criterion to index the file. The use of lines no by themselves does not seem too user-friendly.  I mean, it seemed good to me in the past.  Now that I have a working implementation it feels useless to me :-). Any use case is welcome :-)

GrazianoCapelli, 2017-04-27:
This was thought in order to avoid the ugly buffer flooding that occurs when a whole file is sent.
But this behavior maybe introduces a potential indexing issue (a index is not necessary if the file is opened and sent sequentially, but we have to find a way to restart from the begin of the file), and mainly slows down noticeably the download process.

Maybe we have to find a better way to perform the operation.

JLJu, 2017-05-11:
To be added:
Command to get the log file size in bytes
$LFS

GrazianoCapelli, 2017-05-11:
It is possible to also add a timestamp to message?
Maybe the file creation datetime, or the first (or last) sample datetime.

Something like `$LFA,timestamp,size`.
For example `$LFA,1494365158,12534548`

With the timestamp (and the file size) we could know for sure the following things:
- if a log is already been downloaded by the user.
- if the user added samples to a previous (downloaded) record.

JLJu, 2017-05-11:
It sounds good.
File management system? We will need to restructure the ADCCMS.

To be added
Command to get the required log file size in bytes
msg #22 Request: $LFS, filename
msg #23 Reply: $LFA,1494365158,12534548

To be added
Command to get the list of files on SD card.
msg #20 Request: $LLQ
msg #21 Reply: $LLA,n, filename1, filename2,filename3,filename_n

To be modified to include multiple files

msg  #17 LGD LOG_FILE_DELETE Delete specified log file
msg #18 LGQ LOG_FILE_REQ Ask for specified log file

Filename = Timestamp.csv

Work in progress for new ADCCMS + Lib release.

GrazianoCapelli, 2017-05-11:
In case we opt to implement a sort of file manager, it's also possible, as alternative, to include all commands in one msg header. This way we have a single `$LFA` for answers and a single `$LFQ` for questions.

For example:
`$LFQ,L` Query files (L = List)
`$LFA,L,File1,File2,File3` Answers with the file list

As alternative, we could define the first parameter:
`FILE_LIST = 1`
`NEW_FILE = 2`
`DEL_FILE = 3`
`FILE_PROPERTIES = 4`
and so on

and use them:
`$LFQ,1` Query files
`$LFA,1,File1,File2,File3` Answers with the file list

This way we can start implementing a single command when needed and expand the possibilities in next releases without add / change message set.

JLJu, 2017-05-11:
We need some change, that is unavoidable.
In your scenario, current messages #17, #18 will need to be eliminated. I guess we can replace the old command with the new ones.
As a parameter for LFQ we need to include also:

LOG_FILE_REQ = 5 to get a specified log file
for example $LFQ,5,filename
File list can be then fetched with
$LFQ,1,,  That request msg maintains the same structure at the ADC end and allow for file selection.
For example $LFQ,1,day   can be used to list the files of one specified day.

Given that a parameter will lovely.
ADC code complexity should be kept low as possible, we should avoid complex file handling operations on ADC.

Msgs will be incorporated as soon as ADCCMS is updated.

GrazianoCapelli, 2017-05-11:
In effect we can use messages # 17 and # 18 to perform all operations, it seems a good idea.
For now we could start implementing the following commands:

`FILE_DUMP = 1` to get a specified log file
`FILE_PROPERTIES = 2` to get the properties of the log file

Thus, we'll have the following commands available:

**File dump:**
`$LFQ,1,filename`
_`$LFA,1,Line1`_ first line
_`$LFA,1,Line2`_ second line
_`$LFA,1,Line3`_ third line
_`. . .`_ and so on

**File properties:**
`$LFQ,2,filename`
_`$LFA,2,1494365158,12534548`_ the datetime and the size of the specified file

This way we could start implementing a single file, with a predefined name, in order to test the system.

JLJu, 2017-05-11:
Negative. No file dump per line.

JLJu, 2017-05-11:
Negative. List command missing. No functionalities added respect current implementation.

GrazianoCapelli, 2017-05-11:
I agree, no file dump per line, I intended one message per line.

JLJu, 2017-05-11:
[Tu oder tu nicht. Es gibt kein versuchen!](http://a.dilcdn.com/bl/wp-content/uploads/sites/6/2013/01/yodagerman1.jpg)
Yep, we can use some sort of line breaking. To avoid an eventual flooding it is better to use a soft form of software synchronization. Explicit line ACK should be raw but effective. We will refine the question when we've tested all the other stuff.

JLJu, 2017-05-11:
ADC Common Message Set updated. Library and firmware sketch update will follow.

JLJu, 2017-05-13:
Common Message Set + Library + Sketch updated and working

JLJu, 2017-05-14:
Implemented msg 11, 12, 13

JLJu, 2017-05-15:
Release 0.3 of library is now available. That can be a start point for fine tuning and architetture considerations.

Closed 2018-01-12.

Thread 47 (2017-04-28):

Wrong UOM for deltap sensor and absolute sensor temperature

JLJu, 2017-04-28:
Temperature is calculated and stored in °C. We need to convert to °K.

Closed 2017-04-28.

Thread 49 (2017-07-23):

Sensor socket

JLJu, 2017-07-23:
Sensors loosely connect to the board; here you find the online [PCB 3D model](https://p3d.in/e/lqZsN+spin).
We've found some reliability problem to the prototype.
Obvious, get rid off of the sockets! :-). The point here is to maintain the possibility to remove the sensors. That was a fundamental requirement since the early ADC prototypes, that warrants easy removal for sensor calibration and differential range change. An alternative removable socket/whatever is needed here.

Closed 2017-11-14.

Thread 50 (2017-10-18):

Release Name/Numbers

JLJu, 2017-10-18:
Regarding the ADC hardware, we will switch to a numbering system similar to those used with the software. The current system is not practical under many aspects and lead to users confusion.

Closed 2017-10-20.

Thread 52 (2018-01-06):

Collect and Publish ADC Collected Data

JLJu, 2018-01-06:
We need to make a test run and save all the output and take some pictures/video shoot. The test run will be possibly accompained by position and ground velocity data. All the data should be posted online.

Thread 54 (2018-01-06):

Evaluate IDE Alternative to Upload Firmware to ADC

JLJu, 2018-01-06:
The ADC firmware should usually be compiled and uploaded with Arduino IDE + Teensyduino. It would be lovely to upload the firmware directly to the ADC. That will provide a way to render operative the unit without Arduino IDE nor Teensysuino installed on the machine.

JLJu, 2018-01-07:
Tested this application to upload the firmware (Win 10 /Fedora 27)
https://www.pjrc.com/teensy/loader.html
It eliminates the need for compiling under the Arduino IDE and to copy libraries.  From now on every release should be accompanied by a hex file of the firmware that can be uploaded to the Teensy with the loader software.

Closed 2018-01-12.

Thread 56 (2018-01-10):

Improve the method to check if the SD is present

GrazianoCapelli, 2018-01-10:
The `$FMQ,LST` returns `$FMA,LST,0` in the following cases:
- if the SD is present (inserted) and empty;
- if the SD is not present;

The two cases must be separated.:
- The first case must return `$FMA,LST,0` (zero files present);
- The second case must return `$FMA,LST` (no list: error);

Closed 2018-01-14.

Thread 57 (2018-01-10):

Review the File dump method

GrazianoCapelli, 2018-01-10:
The Dump method (from SD to the serial interfaces) now have some problems:
- It fails on large files because it fills the buffer and discards the data;
- It is a blocking operation that needs the possibility to abort it;

JLJu, 2018-01-10:
Current file download is bulky but easy to implement Teensy side and Android/BT/PC side. Unfortunately, to block the transfer you should cut the power to the ADC.

Move to a standard protocol for file transfer would allow us to use standard serial terminal software, that can be comfortable and also allow automatic scripts to be executed over the serial connection.
Zmodem implementation seems to be available for Teensy
https://forum.pjrc.com/threads/26646-Zmodem-transfer-from-Teensy-to-PC
https://forum.arduino.cc/index.php?topic=382044.0

GrazianoCapelli, 2018-01-10:
For now I implemented an easy way to abort the dump (commit 7319735).

Now it is possible to end the dump anytime, by sending another command from the same serial interface.
The dump will send the `$EOF` sentence and will terminate.
The new command sent will be processed as usual.

It is possible to know if the file is fully downloaded, comparing the remote and the local size.
I take a look to your link and, basing on that code, and I choose to add a periodic `flush()` during the dump process.

The dump method now seems to be rough but fully functional.
To be deeply tested!

JLJu, 2018-01-11:
Way to go!

Closed 2018-01-12.

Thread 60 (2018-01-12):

AirDC Lib  AirDC::ISAAltitude(int mode). Mode=2  missing implementation

JLJu, 2018-01-12:
void AirDC::ISAAltitude(int mode), Case 2.
_uh =0. Implementation should be added.

Closed 2018-01-17.

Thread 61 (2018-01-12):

AirDC::OAT(int mode). mode=1

JLJu, 2018-01-12:
Specific heat ratio value is fixed to a 1.4 value. It should be nice to have a lib function to evaluate the value.

JLJu, 2018-01-17:
Routine tested and saved to
https://github.com/BasicAirData/AirDataComputer/blob/master/Software/Script/Scilab/ADCAsgard/cpcvair.sci
The implementation is planned for the next release of the library

Closed 2018-01-17.

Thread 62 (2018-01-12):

Zeroing the sensors

JLJu, 2018-01-12:
A dedicated message should be added to the communication protocol to handle sensors zeroing and calibration data. That function should work at a raw sensor data level. Let be M the raw sensor reading; the new message should produce a new sensor output Y=a +bM. So the function will be able to change the zero and the span of the sensor measurements. To change the sensor span the user needs a reference instrument. New function should provide  advanced users the possibility to incorporate calibration data/functions/tables(lookup table + interpolation). I will post in brief a possible message format.

JLJu, 2018-01-12:
I will implement a new message (maybe more) that will allow four main functions.

- Trigger a zeroing procedure from attached devices
- Receive calibration data from attached devices and use it on the sensor measurements
- Transmission of current calibration data to the attached devices
- Storage and retrieval of calibration parameters from SD Card, for file transfers we will use the implemented SD dump.

$CCS, SENSOR NUMBER, COMMAND (EXECUTE LOCAL CALIBRATION/USE CALIBRATION DATA FROM THE MESSAGE/SEND OUT CALIBRATION SETUP, MODE (OFFSET/LINEAR), PARAM1, PARAM2

Closed 2018-01-15.

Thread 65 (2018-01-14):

Load a setup configuration file from the SDCard on start

GrazianoCapelli, 2018-01-14:
We need to implement a method to load the setup configuration file on SDCard.
The Air Data Computer could search the file `CONFIG.CFG` into the SDCard on start (a one-time operation, when the user powers the device).
If the file is found, the firmware executes the commands in the file, in the same order they are written.
No additional commands are needed to implement this feature.

Different SDCards can have different setup configuration, depending on the CFG file.

Any software interface can override these settings by send a different configuration as soon as they are connected.

GrazianoCapelli, 2018-01-14:
Feature implemented.
The setup presets file is `CONFIG.CFG`; it must be in the root directory of the SD.

Successfully tested with the following content:
`$DTQ,1,1,1,1,1,1,1,1,1,1,1,1,1,1,1,1,1,1,1,1,1,1,1,1`
`$FMQ,DEL,NEWFILE.CSV`
`$FMQ,NEW,NEWFILE.CSV`
`$LCS,NEWFILE.CSV`
`$DFS,0.5,0,0`

Closed 2018-01-14.

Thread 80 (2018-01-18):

Implement message number 19 and 20

JLJu, 2018-01-18:
Implementation of the messages documented as no. 19 and no. 20 into the
[ADC Common message set](https://github.com/BasicAirData/AirDataComputer/tree/master/Software/Documentation/ADC%20Common%20Message%20Set)

JLJu, 2018-01-21:
To go:
$CCS,USE, needs to be implemented

JLJu, 2018-01-22:
Implementation for msg No.19, command EXE, mode 2 will added in a second stage.

Closed 2018-01-22.

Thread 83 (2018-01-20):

Add files timestamp in the File Manager $FMA messages

GrazianoCapelli, 2018-01-20:
Currently the file name and the size is reported.
Now that the correct timestamp has been implemented, it would be fine to have timestamps in $FMA,LST and $FMA,PRP messages too.

GrazianoCapelli, 2018-02-06:
Timestamps added in `$FMQ,LST` (commit b5ee1cd)
The timestamp must be added in `$FMQ,PRP` too.

GrazianoCapelli, 2018-03-05:
Timestamps added in `$FMQ,PRP` answer too (commit 01faac4).

Closed 2018-03-05.

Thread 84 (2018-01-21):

Return error in $FMQ,NEW if the file already exists

GrazianoCapelli, 2018-01-21:
If the user try to create a new file that already exists, the firmware must return the error `$FMA,NEW`

GrazianoCapelli, 2018-03-05:
Thinking about it, maybe the error message should be reserved in case it is impossible to create the file.
If the file is present after the creation request is processed, the firmware shouldn't return errors.

The user should verify if the file already exists prior to create the new file.

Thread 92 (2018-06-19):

Basic usage of configuration file

JLJu, 2018-06-19:
It is possible to set up ADC initial configuration by mean of a text CFG file write on the microSD.
Within the file, that's the fun part; it's possible to use the same commands available during normal operation mode.
It's nice to post an article on the main site that shows usage and zero offset calibration.

JLJu, 2019-04-16:
Article on the topic
[https://www.basicairdata.eu/projects/airdatacomputer/asgard-adc/example-using-adc-configuration-file-to-compensate-sensor-offset/](https://www.basicairdata.eu/projects/airdatacomputer/asgard-adc/example-using-adc-configuration-file-to-compensate-sensor-offset/)

Closed 2019-04-16.

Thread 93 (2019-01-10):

New Air Data System Layout 1 Work in progress

JLJu, 2019-01-10:
File layout 1
https://github.com/BasicAirData/AirDataComputer/blob/master/Support/Brainstorming/Layout1.pdf
Source included

Layout 1 uses 5v amplified sensors. A dedicated IC performs analog to digital conversion for all sensors signals.
ADS IC had one SPI interface that is read by a Teensy 3.6 Board.
Cost of electronic components  (- Teensy3.6) for airborne application is 310 Eur; bike application components cost 222 Eur
Total Nos. 6 sensors. 55 Eur static + 5X46 Eur DeltaP + 25 Eur ADS
(I will add an accessory voltage regulator soon)

Everything seems to fit together. However, there is an issue here. In the new system layout [the Teensy board is disjoined](https://www.basicairdata.eu/wp-content/uploads/2019/01/Air-Data-System-layout.jpg) from sensors board. That fact implicates that SPI bus should connect two board at a certain distance.

As you know, SPI is not able to cope with long connections.

Now the point.
Should we review the system layout or instead, let's say, fit a supplementary microcontroller near the sensors and equip the communication line with a RS 485 transceiver?

Cheers :-)

Reference Brainstorming URL:
https://www.basicairdata.eu/projects/air-data-systems/brainstorming-air-data-system-winter-2018-2019/

JLJu, 2019-01-13:
5V +  3.3 power on teensy
https://forum.pjrc.com/threads/47966-Teensy-3-6-5V-and-3-3V-workaround

Closed 2019-02-01.

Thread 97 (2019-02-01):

Help with 3D model rendering and publishing

JLJu, 2019-02-01:
[During the brainstorming phase](https://www.basicairdata.eu/projects/air-data-systems/brainstorming-air-data-system-winter-2018-2019/), we often need to play around with 3D models and render. Blender is welcome.
The idea is to provide some graphical follow up.
The final models will be published during the release phase.

Lucasnribeiro, 2019-03-03:
Hi! I have some experience with blender. I could help with modeling + rendering. Though, I never modeled for engineering, wich requires real life accurate measures. Could you give more detail on what you expect to be produced? Thanks!

JLJu, 2019-03-03:
Hi Lucas!
Thank you for your interesting in Basic Air Data.

We miss, but not only, the 3D drawing files of the probes used with the [ADC](https://www.basicairdata.eu/projects/skyeye/review-diy-air-data-computer-asgard-and-pitot-static-on-skyeye-rc-model/) in a neutral format.

1. - [Pitot Probe](http://www.basicairdata.eu/knowledge-center/design/pitot-static-probe/)
   [Reference drawings, page 31/32](http://www.basicairdata.eu/attachments/Manuals/8mmESP-PITOT-Manual.pdf)
   [Reference Github repository](https://github.com/BasicAirData/8mmPitot-StaticProbe)
2. - [Air Data Boom](https://www.basicairdata.eu/projects/air-data-boom/)
[Reference drawings](https://github.com/BasicAirData/AirDataBoom/tree/master/PDFBuildPlans)

For each probe, we need, in this order

1. Each component 3D model
Editable source file
STEP file
STL file

2. Assembly model
Editable source file
STEP file
STL file

3. Animation that illustrates the working principle

Unit of measurement for the drawings models should be millimeters.

For the sake of simplicity, it is better to split the contributions in different pull requests, for example, one component at a time.

Let me know what probe you are willing to contribute to, and I will provide further details.

Lucasnribeiro, 2019-03-04:
Seems that the Pilot Probe could be a nice start. I'm looking at the reference drawing to make the model in Blender with accurate measures.

JLJu, 2019-03-04:
[Have also a look at the pictures of the Pitot](http://www.basicairdata.eu/knowledge-center/design/pitot-static-probe/). The protruding pipe and head are always the same, no matter if a fixation flange is used.

JLJu, 2019-03-04:
P.S. Note that there is some material already posted [in this repo](https://github.com/BasicAirData/8mmPitot-StaticProbe/tree/master/Drawings)

Lucasnribeiro, 2019-03-05:
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

So, I struggled a bit to understand how engineering drawing works. Did some mistakes with the diameters and took longer than I expected. But at the moment im almost certain that it is accurate.

I was modeling based only on the drawings, but now that i've downloaded the STL files that you already had it made things more clear. Like the holes ( that I need to make ) on the main tube. They go around it all the way.

But comparing the amount of faces on the STL model and the one that i've made we can see an improvement. The only thing that is concerning me right now is that Blender can't output STEP files. Only STL. Reading online I've found that CAD programs can convert STL to STEP, but since I never used CAD software before I imagine that you could give some help with it.

Here's the model so far: https://ufile.io/xwntq

I still have to make some adjustments, but all the measures are as the drawings. Scale is in mm.

JLJu, 2019-03-06:
Nice!
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
Is it possible to have separate surfaces for the different parts? I mean, the pitot head part seems flat at bottom.

A little background. The models you are working on are intended to be used for virtual assembly, 3D print,  web illustrations, videos of working principle ([check this out, not a pitot :-)](https://youtu.be/oUd4WxjoHKY?t=81)), and general render with the ADC.

Freecad(that is free) is able to convert STL to STEP, it's not a concern right now.

Lucasnribeiro, 2019-03-06:
Oh Im sorry for that. The flat bottom is because I have different layers on the Blender project and STL export probably doesn't support saving just one of them and saves it all merged. But the correct model has the holes.

The pitot is a separate part, so as the body and the inner tube. They can all be separated, cut and edited. When finished I will create files for each of them.

JLJu, 2019-03-06:
It's okay. I think it is better to focus on the model for the pitot without flange (page 31). This probe has a visible epoxy sealing at one end of the main 8 mm pipe.
Regards

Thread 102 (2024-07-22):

USE of stm32 as a microcontroller

Taskeenriaz, 2024-07-22:
If you are reporting a bug please send to us this information
## Hardware/Probe/Firmware description
## Unexpected Behavior
## How to reproduce the issue

Taskeenriaz, 2024-07-22:
hi,
I want to change microcontroller and replace stm32 , now the problem is that I also want i2c and can communication rather than Bluetooth as I want to connect this with autopilot px4 so it any thing that will work for me .. or how I do this

Taskeenriaz, 2024-07-23:
firstly thankyou for the help , yes so I need tp use stm32f401 series chip all I want is to make a ADU and integrate it with the pixhawk secondly I don't need Bluetooth and I want to connect through i2c so I want to  do this.

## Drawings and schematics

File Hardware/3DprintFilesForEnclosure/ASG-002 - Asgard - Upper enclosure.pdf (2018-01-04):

M-M ( 2 : 1 )

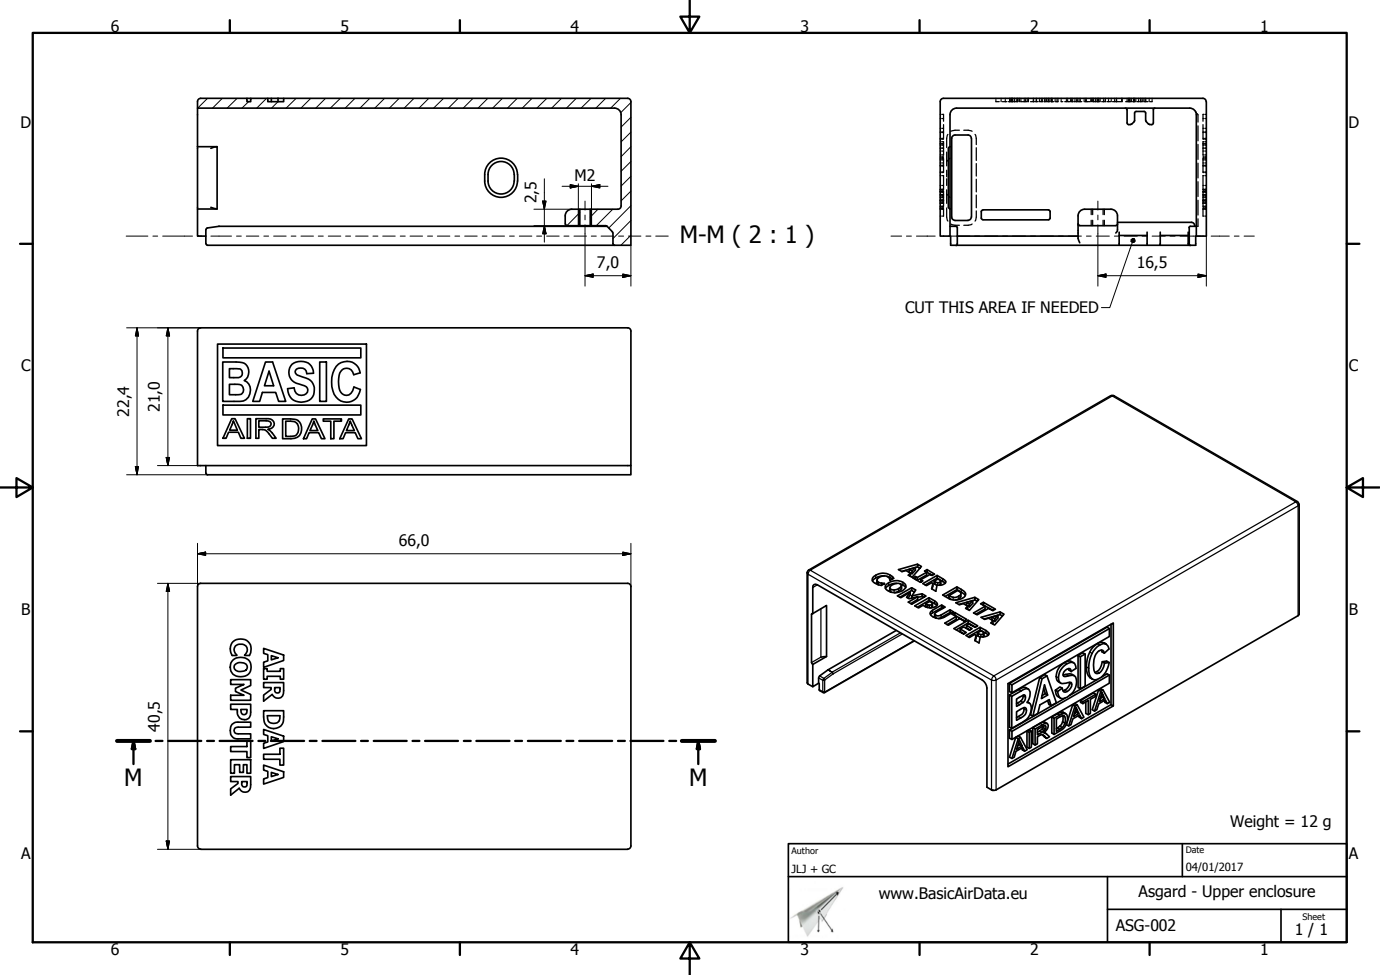
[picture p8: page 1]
ASG-002; JLJ + GC; Author; Date; Sheet; Weight = 12 g

CUT THIS AREA IF NEEDED

www.BasicAirData.eu

Asgard - Upper enclosure

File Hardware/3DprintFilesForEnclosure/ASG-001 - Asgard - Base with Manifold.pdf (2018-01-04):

L-L ( 2 : 1 )

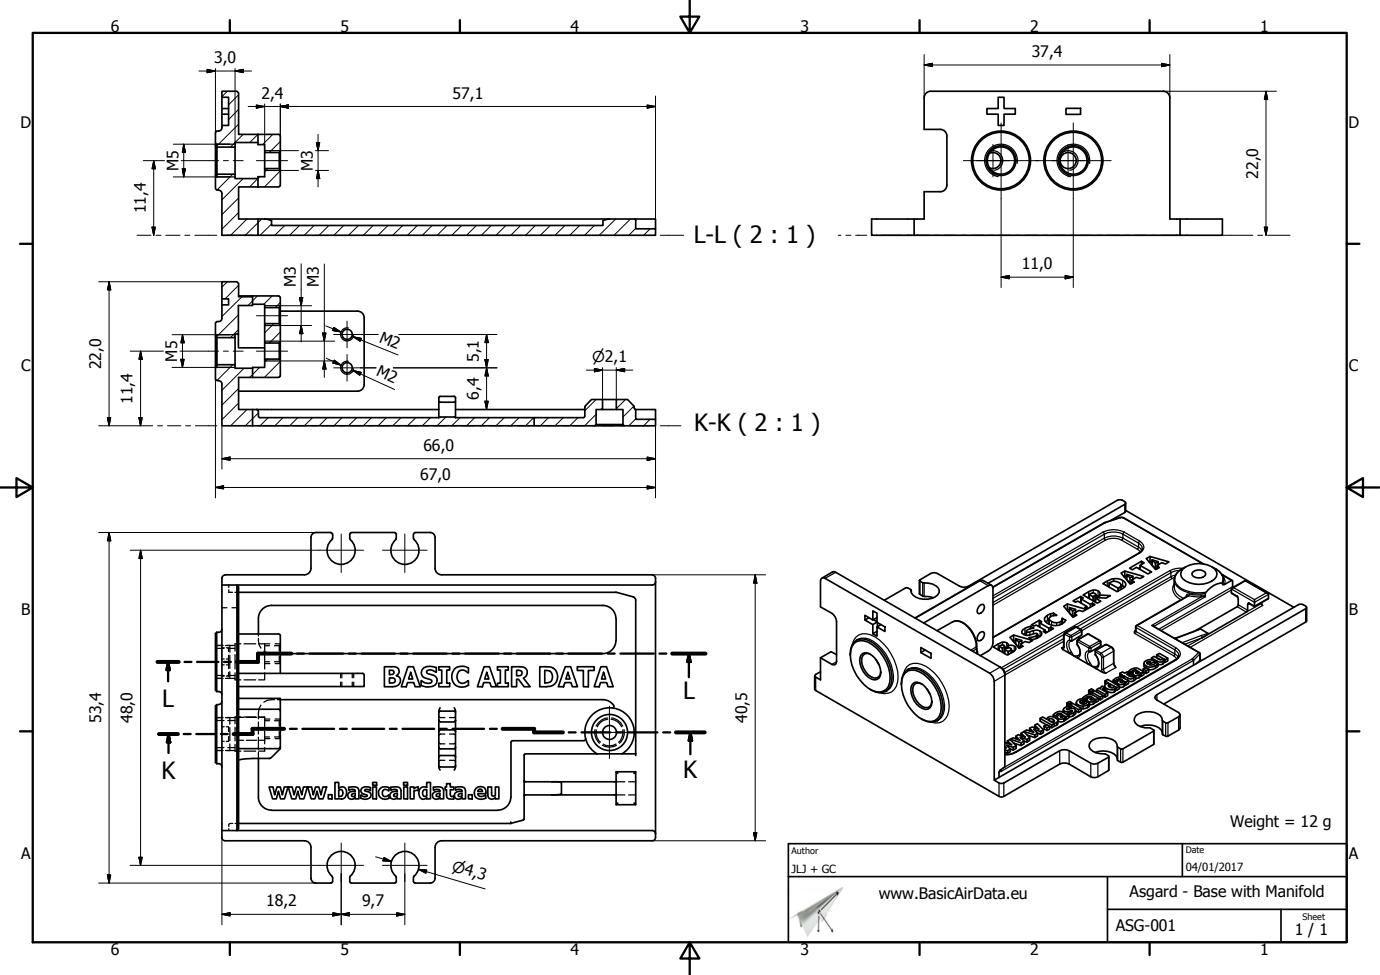
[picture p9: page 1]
ASG-001; JLJ + GC; Author; Date; Sheet; Weight = 12 g

www.BasicAirData.eu

Asgard - Base with Manifold

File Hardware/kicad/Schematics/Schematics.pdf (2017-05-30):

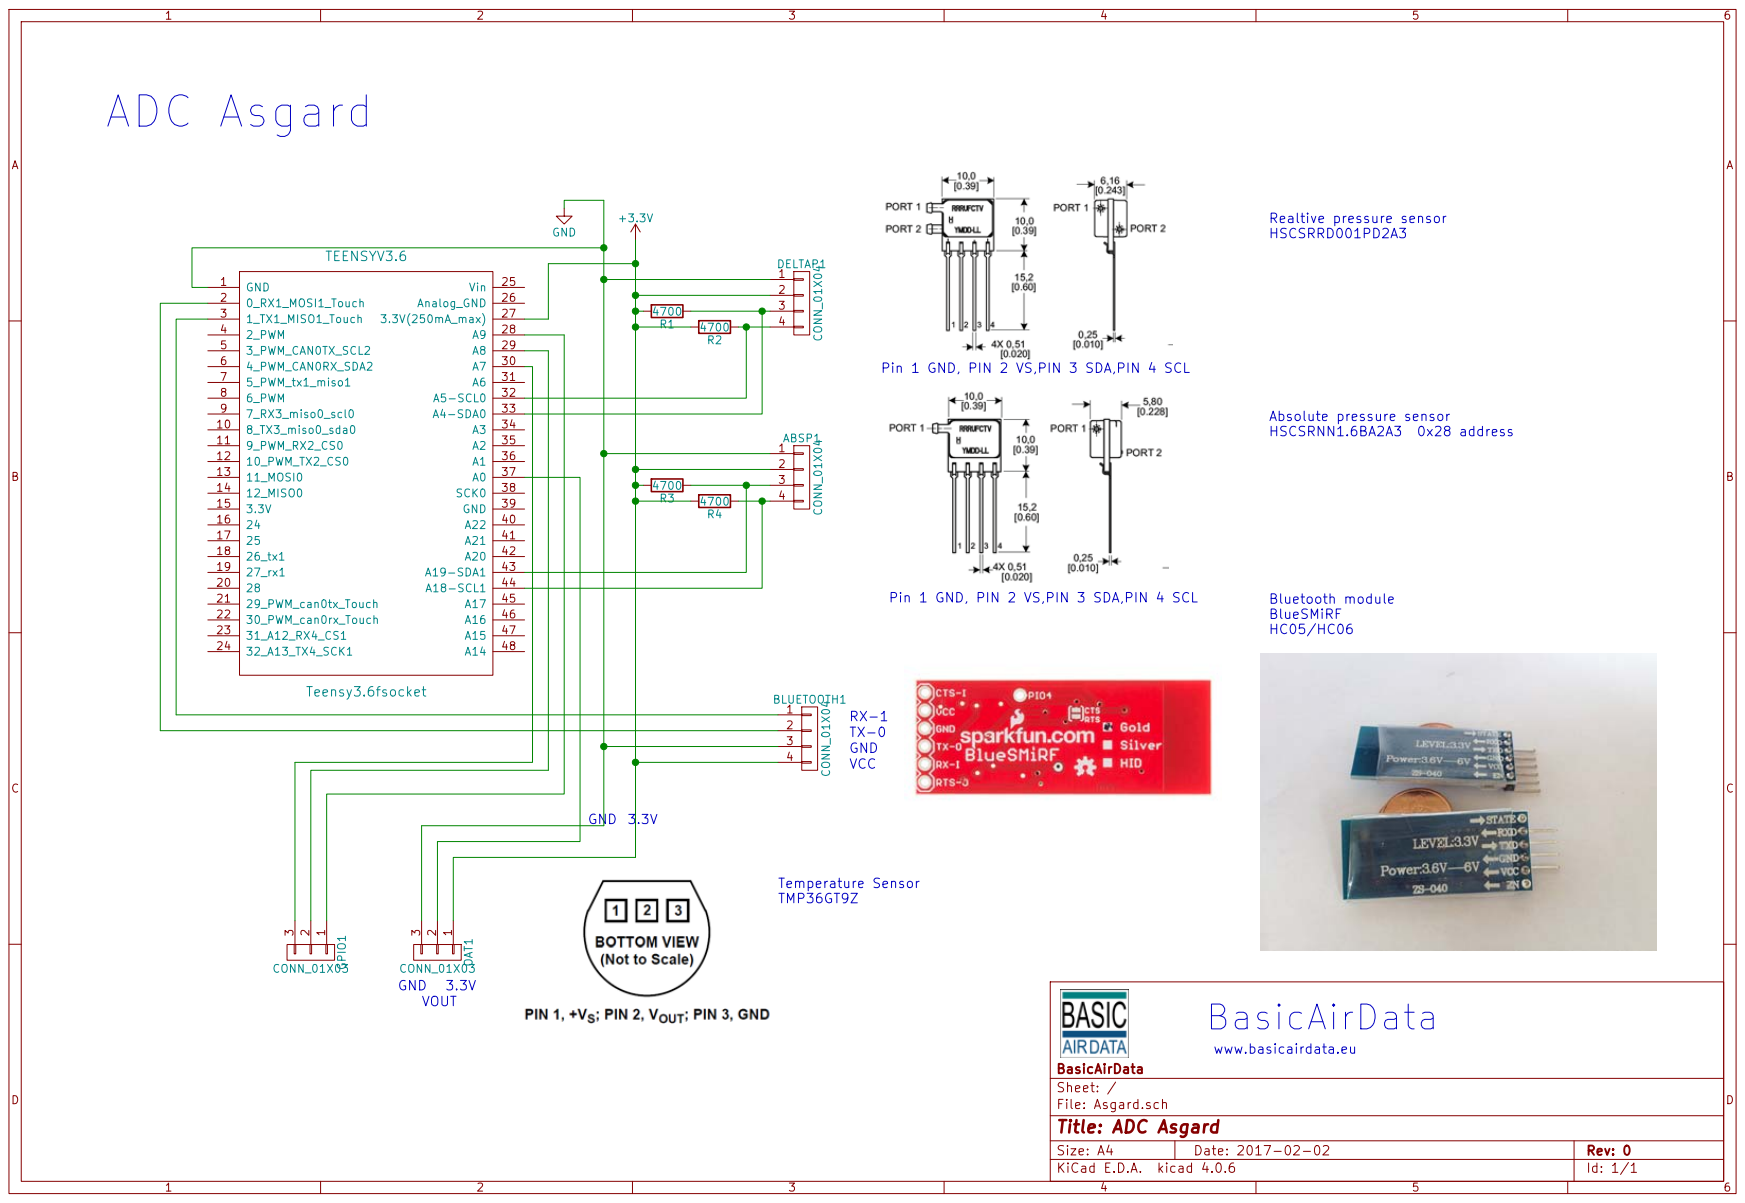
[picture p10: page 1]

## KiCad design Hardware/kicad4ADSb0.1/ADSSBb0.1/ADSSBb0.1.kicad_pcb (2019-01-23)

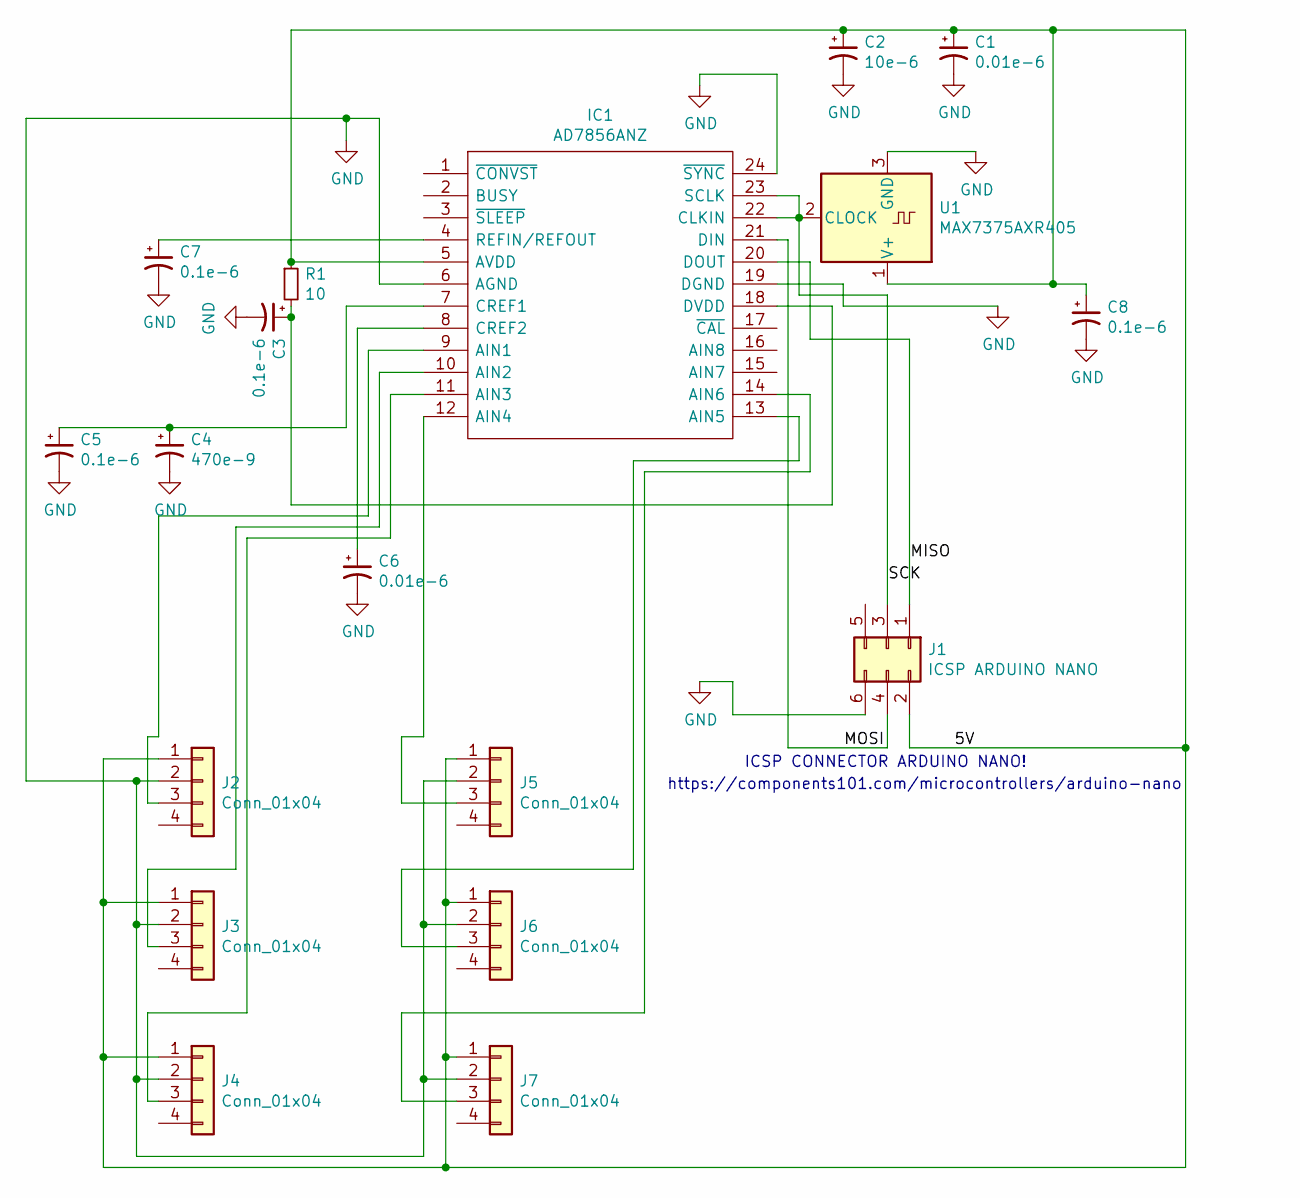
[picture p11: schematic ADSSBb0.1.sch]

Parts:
C1, C6: 0.01e-6; CP_Radial_D4.0mm_P1.50mm
C2: 10e-6; CP_Radial_D4.0mm_P1.50mm
C3, C5, C7, C8: 0.1e-6; CP_Radial_D4.0mm_P1.50mm
C4: 470e-9; CP_Radial_D4.0mm_P1.50mm
IC1: AD7856ANZ; DIP-24_W10.16mm; Mouser Part Number 584-AD7856ANZ
J1: ICSP ARDUINO NANO; PinSocket_2x03_P2.54mm_Vertical
J2, J3, J4, J5, J6, J7: Conn_01x04; PinSocket_1x04_P2.54mm_Vertical
R1: 10; R_Axial_DIN0204_L3.6mm_D1.6mm_P1.90mm_Vertical
U1: MAX7375AXR405; SOT-323_SC-70

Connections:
/5V: C1.1, C2.1, C8.1, IC1.5 (AVDD), J1.2, J2.1, J3.1, J4.1, J5.1, J6.1, J7.1, R1.1, U1.1 (V+)
/MISO: IC1.20 (DOUT), J1.1
/MOSI: IC1.21 (DIN), J1.4
/SCK: IC1.22 (CLKIN), IC1.23 (SCLK), J1.3, U1.2 (CLOCK)
GND: C1.2, C2.2, C3.2, C4.2, C5.2, C6.2, C7.2, C8.2, IC1.6 (AGND), IC1.19 (DGND), IC1.24 (~SYNC), J1.6, J2.2, J3.2, J4.2, J5.2, J6.2, J7.2, U1.3 (GND)
unnamed: C3.1, IC1.18 (DVDD), R1.2
unnamed: C4.1, C5.1, IC1.7 (CREF1)
unnamed: C6.1, IC1.8 (CREF2)
unnamed: C7.1, IC1.4 (REFIN/REFOUT)
unnamed: IC1.9 (AIN1), J2.3
unnamed: IC1.10 (AIN2), J3.3
unnamed: IC1.11 (AIN3), J4.3
unnamed: IC1.12 (AIN4), J5.3
unnamed: IC1.13 (AIN5), J6.3
unnamed: IC1.14 (AIN6), J7.3

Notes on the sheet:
https://components101.com/microcontrollers/arduino-nano
ICSP CONNECTOR ARDUINO NANO!

Board: 2 copper layers, 18 parts (3 on the bottom side), 15 nets, no tracks yet.

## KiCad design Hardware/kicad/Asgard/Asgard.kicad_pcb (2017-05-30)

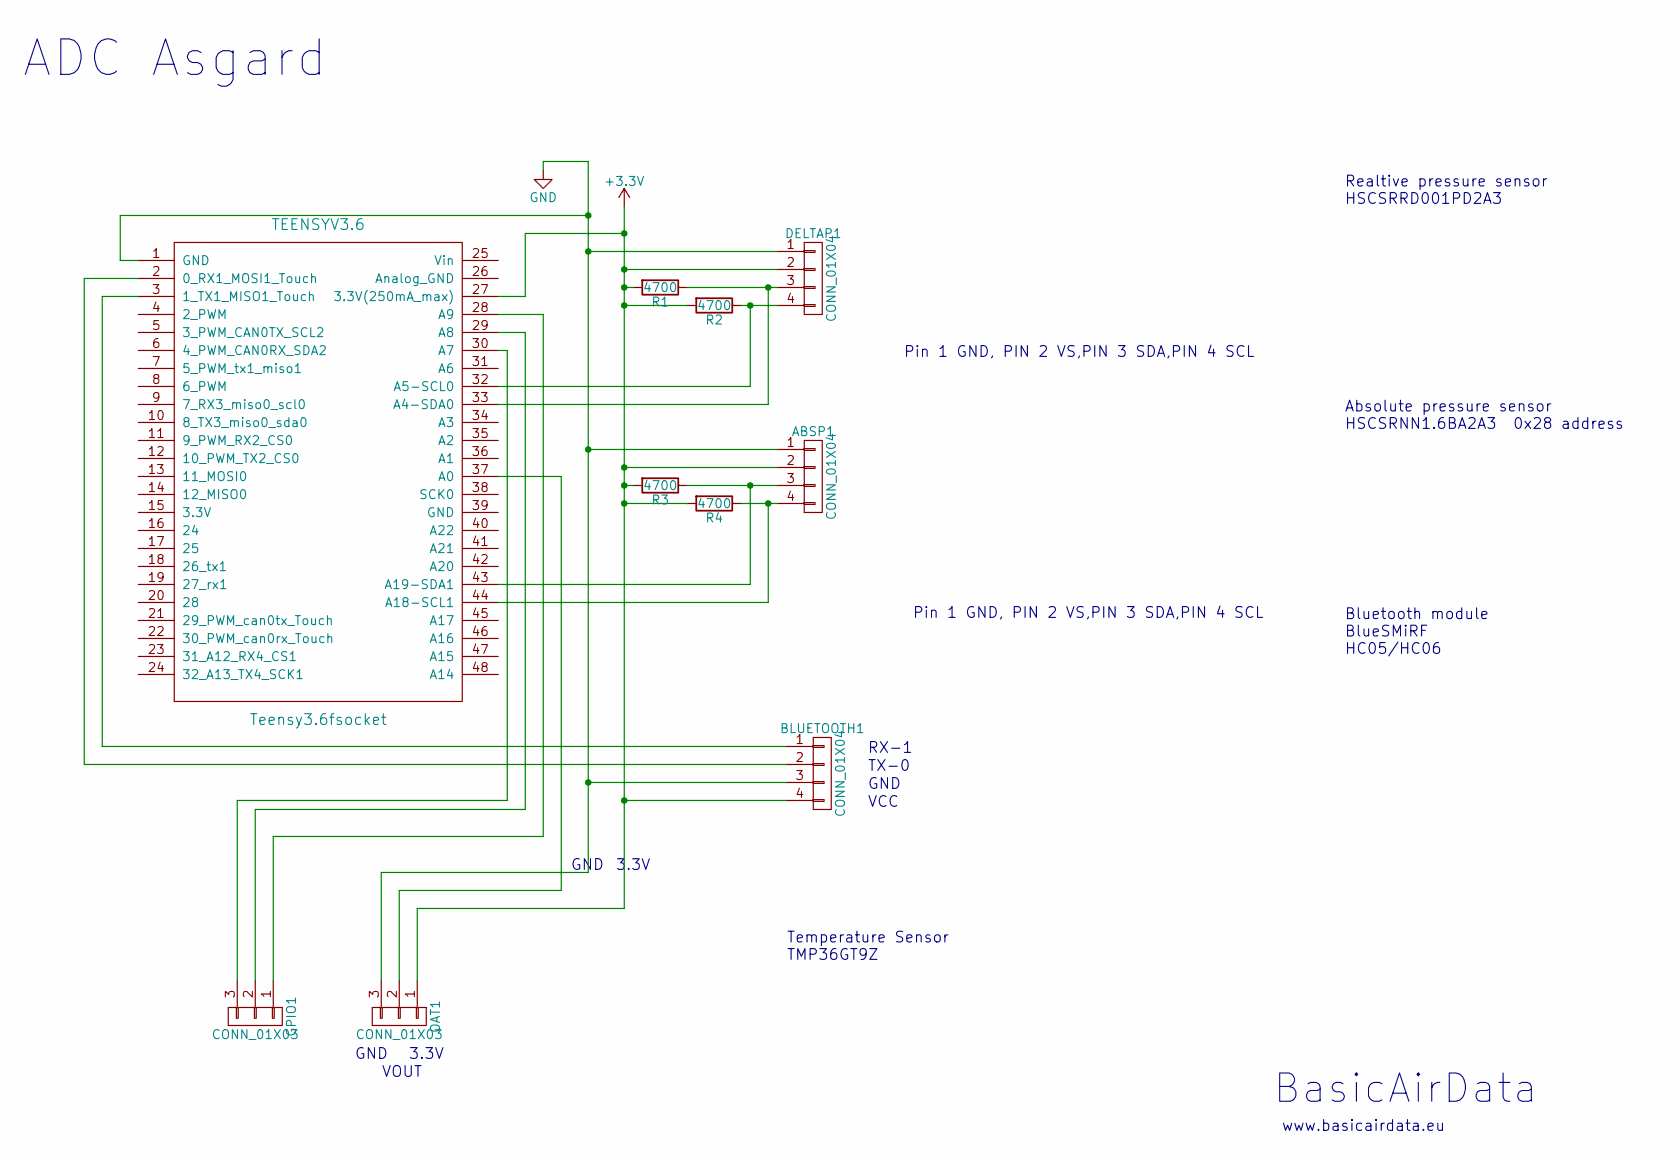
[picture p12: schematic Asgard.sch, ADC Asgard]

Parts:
ABSP1: CONN_01X04; Socket_Strip_Straight_1x04_Pitch2.54mm
BLUETOOTH1: CONN_01X04; Socket_Strip_Straight_1x04_Pitch2.54mm
DELTAP1: CONN_01X04; Socket_Strip_Straight_1x04_Pitch2.54mm
GPIO1: CONN_01X03; PINHEAD1-3
OAT1: CONN_01X03; PINHEAD1-3
R1, R2, R3, R4: 4700; R_Axial_DIN0204_L3.6mm_D1.6mm_P1.90mm_Vertical
TEENSYV3.6: Teensy3.6fsocket; Socket_Strip_Teensy3.6_2x24_Pitch2.54mm

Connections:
+3V3: ABSP1.2, BLUETOOTH1.4, DELTAP1.2, OAT1.1, R1.2, R2.2, R3.2, R4.2, TEENSYV3.6.27 (3.3V(250mA_max))
GND: ABSP1.1, BLUETOOTH1.3, DELTAP1.1, OAT1.3, TEENSYV3.6.1 (GND)
unnamed: ABSP1.3, R3.1, TEENSYV3.6.43 (A19-SDA1)
unnamed: ABSP1.4, R4.1, TEENSYV3.6.44 (A18-SCL1)
unnamed: BLUETOOTH1.1, TEENSYV3.6.3 (1_TX1_MISO1_Touch)
unnamed: BLUETOOTH1.2, TEENSYV3.6.2 (0_RX1_MOSI1_Touch)
unnamed: DELTAP1.3, R1.1, TEENSYV3.6.33 (A4-SDA0)
unnamed: DELTAP1.4, R2.1, TEENSYV3.6.32 (A5-SCL0)
unnamed: GPIO1.1, TEENSYV3.6.28 (A9)
unnamed: GPIO1.2, TEENSYV3.6.29 (A8)
unnamed: GPIO1.3, TEENSYV3.6.30 (A7)
unnamed: OAT1.2, TEENSYV3.6.37 (A0)

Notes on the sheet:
BasicAirData
RX-1
TX-0
GND
VCC
Absolute pressure sensor HSCSRNN1.6BA2A3 0x28 address
Realtive pressure sensor HSCSRRD001PD2A3
Bluetooth module BlueSMiRF HC05/HC06
Pin 1 GND, PIN 2 VS,PIN 3 SDA,PIN 4 SCL
ADC Asgard
www.basicairdata.eu
Temperature Sensor TMP36GT9Z
3.3V
VOUT

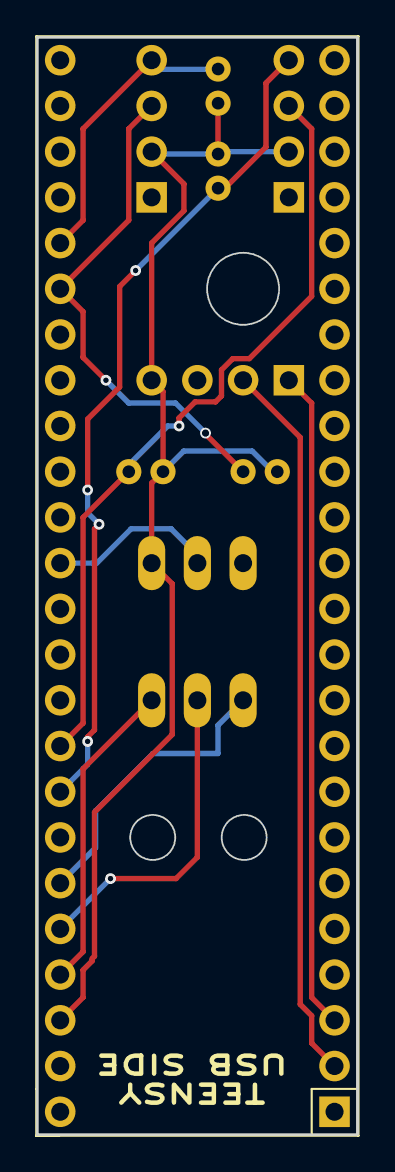
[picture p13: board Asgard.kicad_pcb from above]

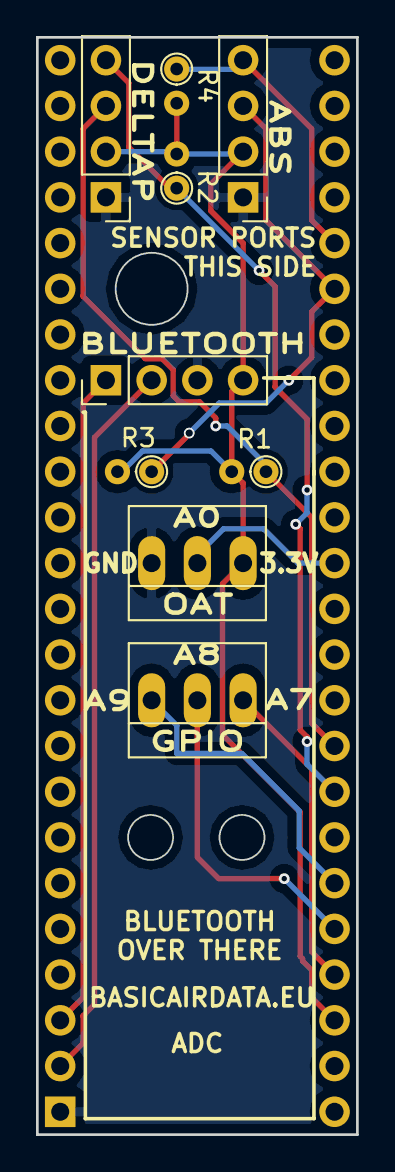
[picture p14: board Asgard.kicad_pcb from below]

Board: 2 copper layers, 17.8 x 61.0 mm, 10 parts (9 on the bottom side), 12 nets.

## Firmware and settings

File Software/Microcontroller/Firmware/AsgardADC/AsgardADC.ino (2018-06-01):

/* Work in progress Asgard ADC Firmware Relase 0.5.0 08/02/2018
   This is a preliminary release, work in progress. Misbehaviour is plausible.
   AsgardADC.ino - Air Data Computer Firmware
   Conform to ADC Common Mesage Set 0.5
   Firmware for Teensy 3.6 MCU
   Created by JLJ and GC, BasicAirData Team www.basicairdata.eu

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
   You should have received a copy of the GNU General Public License
   along with this program. If not, see <http://www.gnu.org/licenses/>.
*/

#include <Time.h>
#include <TimeLib.h>
#include <Metro.h>
#include <AirDC.h>
#include <SD.h>
#include <SPI.h>
#include <SD_t3.h>
#include <i2c_t3.h>                       // Library for second I2C 
#include <SSC.h>                          // Library for SSC series sensors, support two bus I2C

#define ADC_NAME "ASGARD"                 // The name of the ADC device
#define PROTOCOL_VERSION "0.5"            // The version of the communication protocol

#define BUFFERLENGTH 2048                 // The length of string buffers
#define DELIMITER '\n'
#define SEPARATOR ","
#define LEAVE_AS_IS "="
#define DEFAULT_LOGFILE "DATALOG.CSV"     // The default log file name
#define DEFAULT_CONFIGFILE "CONFIG.CFG"   // The configuration file name

const int ledPin      = 13;               // The led is ON when the application is logging on SD
const int TsensorPin  = A0;               // The input pin for the analog Temperature sensor
const int chipSelect  = BUILTIN_SDCARD;   // HW pin for micro SD adaptor CS

File dataFile;                            // The file on SD
File configFile;                          // The setup configuration file on SD
bool isSDCardPresent;                     // The presence of a (formatted) card into the slot of SD
bool loadConfiguration;                   // The flag is true if the config file is present into SD (and must be loaded on start)
Sd2Card card;                             // The SD Card
SdVolume volume;                          // The volume (partition) on SD
double iTAS, ip1TAS, res, iof;            // Accessory variables for Air Data calculations

float diffpMinRaw          =   1638.3; //Declaration of sensors specific parameters for default ADC configuration
float diffpMaxRaw          =   14744.7;
float diffpMinPressure     =   -6984.760;
float diffpsetMaxPressure  =   6984.760;
float absMinRaw            =   1638.3;
float absMaxRaw            =   14744.7;
float absMinPressure       =   0.0;
float abssetMaxPressure    =   160000.0;

AirDC AirDataComputer(1);     // The Air Data Computer

SSC diffp(0x28, 0);           // Create an SSC sensor with I2C address 0x28 on I2C bus 0
SSC absp(0x28, 1);            // Create an SSC sensor with I2C address 0x28 on I2C bus 1

String message_BT;            // string that stores the incoming BT message
String message_COM;           // string that stores the incoming COM message
String message_CFG;           // string that stores the configuration messages

float acquisition_freq     =   1;         // The minimum frequency of acquisition = 1 Hz (1 s)
float sendtoserial_freq    =   0;         // The frequency of sendtoserial        = NOT ACTIVE
float sendtobluetooth_freq =   0;         // The frequency of sendtobluetooth     = NOT ACTIVE
float sendtosd_freq        =   0;         // The frequency of sendtosd,           = NOT ACTIVE

long acquisition_interval  = (long)(1.0f / acquisition_freq * 1000.0f);
long sendtoserial_interval;
long sendtobluetooth_interval;
long sendtosd_interval;

int delaymicroseconds_interval = 5000;    // The delay at the end of main loop. It may vary in the range 100-5000 micros.

Metro acquisitionTimer     = Metro(acquisition_interval);             // The timer for acquisition
Metro sendtoserialTimer    = Metro(sendtoserial_interval);            // The timer for sendtoserialTimer
Metro sendtobluetoothTimer = Metro(sendtobluetooth_interval);         // The timer for sendtobluetoothTimer
Metro sendtosdTimer        = Metro(sendtosd_interval); //NOT ACTIVE   // The timer for sendtosdTimer

bool sendtoserial_needs_acquisition    = true;    // The check that the aquisition has been updated since the last $DTA
bool sendtobluetooth_needs_acquisition = true;    // The check that the aquisition has been updated since the last $DTA
bool sendtosd_needs_acquisition        = true;    // The check that the aquisition has been updated since the last $DTA

char Data[2][BUFFERLENGTH];  // The strings containing the data message
char *p_Data;                // The pointer to the current valid data string





void setup() {
  // Deafult configuration for ADC Hardware. 1 present; 0 not installed
  AirDataComputer._status[AIRDC_STATUS_SD]        = '0'; // SD Card
  AirDataComputer._status[AIRDC_STATUS_DELTAP]    = '1'; // Deltap pressure sensor
  AirDataComputer._status[AIRDC_STATUS_P]         = '1'; // Absolute pressure sensor
  AirDataComputer._status[AIRDC_STATUS_TAT]       = '1'; // External temperature sensor
  AirDataComputer._status[AIRDC_STATUS_TDELTAP]   = '1'; // Deltap sensor temperature
  AirDataComputer._status[AIRDC_STATUS_TABSP]     = '1'; // Absolute pressure sensor temperature
  AirDataComputer._status[AIRDC_STATUS_RTCBATT]   = '0'; // Real time clock temperature temperature
  AirDataComputer._status[AIRDC_STATUS_ERRWARN]   = '0'; // Error/Warning
  AirDataComputer._status[AIRDC_STATUS_BLUETOOTH] = '0'; // BT Module present on serial1

  strcpy(AirDataComputer._logfile, DEFAULT_LOGFILE);

  pinMode(TsensorPin, INPUT);
  pinMode(ledPin, OUTPUT);

  Serial.begin (57600);                             // Set up the Serial Connection using high speed, for precise log timings
  //Serial.begin (9600);                            // Set up the Serial Connection
  Serial1.begin (9600);                             // Set up the BT Connection
  delay(500);
  if (Serial1) AirDataComputer._status[AIRDC_STATUS_BLUETOOTH] = '1';    // BT Module present on serial1

  SDCardCheck();

  Wire.begin();                     // I2C Bus 0
  Wire1.begin();                    // I2C Bus 1

  // Setup sensors parameters
  diffp.setMinRaw (diffpMinRaw);
  diffp.setMaxRaw (diffpMaxRaw);
  diffp.setMinPressure (diffpMinPressure);
  diffp.setMaxPressure (diffpsetMaxPressure);
  absp.setMinRaw (absMinRaw);
  absp.setMaxRaw (absMaxRaw);
  absp.setMinPressure (absMinPressure);
  absp.setMaxPressure (abssetMaxPressure);

  strcpy(Data[0], "\0");     // Initialize the Data
  strcpy(Data[1], "\0");     // Initialize the Data
  p_Data = &Data[1][0];      // The current valid status index is 1

  if (isSDCardPresent) {     // Searches the configuration file
    configFile = SD.open(DEFAULT_CONFIGFILE);
    if (configFile) loadConfiguration = true;
  }
}



void getNextFilename(char* namefile)
{
  if (strlen(namefile) < 13) {
    char namefile1[13], newname[13], number[13], nformat[5], *before, *after;
    int numbersize = 13 - strlen(namefile);
    numbersize = min (numbersize, 4);
    sprintf(nformat, "%%0%id", numbersize);
    strcpy(namefile1, namefile);
    before = strtok (namefile1, "?");
    after = strtok (NULL, "?");
    bool fileexists = true;
    for (int i = 0; i < (pow(10, numbersize)) && fileexists; i++) {
      sprintf(number, nformat, i);
      strcpy(newname, before);
      strcat(newname, number);
      strcat(newname, after);
      if (!SD.exists(newname)) {
        strcpy(namefile, newname);
        fileexists = false;
      }
    }
  }
}


void dateTime(uint16_t* date, uint16_t* time)                 // Callback for file timestamps
{
  *date = FAT_DATE(year(), month(), day());
  *time = FAT_TIME(hour(), minute(), second());
}



void SDCardCheck()
{
  if (!isSDCardPresent) {
    isSDCardPresent = card.init(SPI_FULL_SPEED, chipSelect);
    if (isSDCardPresent) SD.begin(chipSelect);
  }
  isSDCardPresent = volume.init(card);
  AirDataComputer._status[AIRDC_STATUS_SD] = (isSDCardPresent ? '1' : '0');
}



void acquisition()
{
  // 1) Sensors reading

  // Outside Temperature Sensor
  if (AirDataComputer._status[AIRDC_STATUS_TAT] == '1') {   // External Temperature sensor present
    AirDataComputer._TRaw = analogRead(TsensorPin);
    AirDataComputer._TAT = ((((AirDataComputer._TRaw * (3300.0 / 1024)) - 750) / 10) + 25) + 273.15; // Total Air Temperature
  }

  // Differential Pressure sensor
  if (AirDataComputer._status[AIRDC_STATUS_DELTAP] == '1') {     // Differential pressure sensor present
    diffp.update();
    //AirDataComputer._qc = diffp.pressure();
    AirDataComputer._qc = AirDataComputer.CorrectDp(1, diffp.pressure()); //Corrected Differential Pressure
    AirDataComputer._qcRaw = diffp.pressure_Raw();
    if (AirDataComputer._status[AIRDC_STATUS_TDELTAP] == '1') {   // Temperature differential pressure sensor present
      AirDataComputer._Tdeltap = diffp.temperature();
      AirDataComputer._TdeltapRaw = diffp.temperature_Raw();
    }
  }

  // Absolute Pressure sensor
  if (AirDataComputer._status[AIRDC_STATUS_P] == '1') {           // Absolute pressure sensor present
    absp.update();
    AirDataComputer._pRaw = absp.pressure_Raw();
    AirDataComputer._p = absp.pressure();
    if (AirDataComputer._status[AIRDC_STATUS_TABSP] == '1') {     // Temperature absolute pressure sensor present
      AirDataComputer._Tabsp = absp.temperature();
      AirDataComputer._TabspRaw = absp.temperature_Raw();
    }
  }

  // No sensor for RH, we are selecting dry air but the library will handle moist air if required
  AirDataComputer._RH = 0;

  // For low speeds this is a good approximation
  AirDataComputer._T = AirDataComputer._TAT;


  // 2) Calculations

  // Init
  AirDataComputer.RhoAir(1);                    // Calculates the air density
  AirDataComputer.Viscosity(1);                 // Calculates the dynamic viscosity, Algorithm 2 (UOM Pas1e-6)
  AirDataComputer.CalibrationFactor(1);         // Calibration factor set to 1
  AirDataComputer.IAS(1);                       // Calculates IAS method 1
  AirDataComputer._TAS = AirDataComputer._IAS;
  AirDataComputer.Mach(1);                      // Calculates Mach No
  AirDataComputer.OAT(1);                       // Outside Air Temperature
  // Wild iteration
  iof = 1;
  while ((res > 0.05) || (iof < 10)) {
    AirDataComputer.RhoAir(1);                  // Calculates the air density
    AirDataComputer.Viscosity(1);               // Calculates the dynamic viscosity, Algorithm 2 (UOM Pas1e-6)
    AirDataComputer.CalibrationFactor(2);       // Update calibration fator vat at TAS
    AirDataComputer.IAS(1);                     // IAS
    AirDataComputer.CAS(1);                     // CAS
    AirDataComputer.TAS(1);                     // True Air Speed
    AirDataComputer.Mach(1);                    // Update Mach No
    iTAS = AirDataComputer._TAS;                // Store TAS value
    AirDataComputer.OAT(1);                     // Update outside Air Temperature
    AirDataComputer.RhoAir(1);                  // Calculates the air density
    AirDataComputer.Viscosity(1);               // Calculates the dynamic viscosity, Algorithm 2 (UOM Pas1e-6)
    AirDataComputer.CalibrationFactor(2);       // Update calibration fator vat at TAS
    AirDataComputer.TAS(1);                     // Update TAS
    AirDataComputer.Mach(1);                    // Update Mach No
    AirDataComputer.OAT(1);                     // Update outside Air Temperature
    ip1TAS = AirDataComputer._TAS;
    res = abs(ip1TAS - iTAS) / iTAS;
    iof++;
  }
  // Uncorrected ISA Altitude _h
  AirDataComputer.ISAAltitude(1);
  AirDataComputer._d = 8e-3;
  AirDataComputer.Red(1);


  // 3) $DTA message update

  char *p_newData;                                                  // The pointer to unused index;
  p_newData = (p_Data == &Data[0][0] ? &Data[1][0] : &Data[0][0]);  // The new string is composed into the unused Data index
  strcpy (p_newData, "$DTA");

  char workbuff[BUFFERLENGTH];                                      // General purpose buffer, used for itoa conversion
  AirDataComputer.PrepareData();

  for (int i = 0; i < AIRDC_DATA_VECTOR_SIZE; i++) {                // Prepare to send #10 - DTA - DATA_ASSERT message
    strcat (p_newData, SEPARATOR); // Add the separator
    if (AirDataComputer._datasel[i] == '1') {
      switch (i) {
        case AIRDC_DATA_TIME:
        case AIRDC_DATA_QCRAW:
        case AIRDC_DATA_PRAW:
        case AIRDC_DATA_TRAW:
        case AIRDC_DATA_TDELTAPRAW:
        case AIRDC_DATA_TABSPRAW:
        case AIRDC_DATA_MILLIS:
          sprintf(workbuff, "%.0f", (AirDataComputer._dataout[i])); break;

        case AIRDC_DATA_P:
        case AIRDC_DATA_TAT:
        case AIRDC_DATA_TDELTAP:
        case AIRDC_DATA_TABSP:
        case AIRDC_DATA_UIAS:
        case AIRDC_DATA_UTAS:
        case AIRDC_DATA_UH:
        case AIRDC_DATA_UT:
        case AIRDC_DATA_T:
        case AIRDC_DATA_RE:
          sprintf(workbuff, "%.1f", (AirDataComputer._dataout[i])); break;

        case AIRDC_DATA_IAS:
        case AIRDC_DATA_TAS:
        case AIRDC_DATA_H:
        case AIRDC_DATA_QC:
          sprintf(workbuff, "%.2f", (AirDataComputer._dataout[i])); break;

        case AIRDC_DATA_C:
          sprintf(workbuff, "%.4f", (AirDataComputer._dataout[i])); break;

        case AIRDC_DATA_RHO:
          sprintf(workbuff, "%.6f", (AirDataComputer._dataout[i])); break;

        case AIRDC_DATA_MU:
          sprintf(workbuff, "%.8f", (AirDataComputer._dataout[i])); break;

        default:
          sprintf(workbuff, "%f", (AirDataComputer._dataout[i])); break;   // UNUSED DEFAULT FORMAT
      }
      strcat (p_newData, workbuff);
    } else {
    }
  }
  strcat (p_newData, "\0");

  p_Data = (p_Data == &Data[0][0] ? &Data[1][0] : &Data[0][0]);   // Switch the pointer to the current valid string to the new one

  sendtoserial_needs_acquisition      = false;    // The aquisition has been updated since the last $DTA
  sendtobluetooth_needs_acquisition   = false;    // The aquisition has been updated since the last $DTA
  sendtosd_needs_acquisition          = false;    // The aquisition has been updated since the last $DTA
}



void sendtoserial(void)
{
  char printdata[BUFFERLENGTH];
  strcpy (printdata, p_Data);
  sendtoserial_needs_acquisition = true;
  Serial.println(printdata);
}



void sendtobluetooth(void)
{
  char printdata[BUFFERLENGTH];
  strcpy (printdata, p_Data);
  sendtobluetooth_needs_acquisition = true;
  Serial1.println(printdata);
}



void sendtosd(void)
{
  char printdata[BUFFERLENGTH];
  strcpy (printdata, p_Data);
  sendtosd_needs_acquisition = true;
  if (dataFile) dataFile.println(printdata);
}



void loop() {
  bool endmsg_BT                = false;  // it becomes true when a message is received from BLUETOOTH
  bool endmsg_COM               = false;  // it becomes true when a message is received from SERIAL
  bool endmsg_CFG               = false;  // it becomes true when a message is received from CONFIGURATION FILE
  char workbuff[BUFFERLENGTH]   = "";     // General purpose buffer, used for itoa conversion
  char Message[BUFFERLENGTH]    = "";     // it contains the message to be processed
  char Answer[BUFFERLENGTH]     = "";     // it contains the answer to the message


  // 0) Check Metro Timers:

  if ((acquisition_freq > 0) && (acquisitionTimer.check() == 1)) acquisition();

  if ((sendtoserial_freq > 0) && (sendtoserialTimer.check() == 1)) {
    if (sendtoserial_needs_acquisition) {
      acquisition();
      acquisitionTimer.reset();
    }
    sendtoserial();
  }

  if ((sendtobluetooth_freq > 0) && (sendtobluetoothTimer.check() == 1)) {
    if (sendtobluetooth_needs_acquisition) {
      acquisition();
      acquisitionTimer.reset();
    }
    sendtobluetooth();
  }

  if ((sendtosd_freq > 0) && (sendtosdTimer.check() == 1)) {
    if (sendtosd_needs_acquisition) {
      acquisition();
      acquisitionTimer.reset();
    }
    sendtosd();
  }


  // 1) Read input from Configuration file, Serial, and Bluetooth:

  if (loadConfiguration) {
    while (configFile.available()) {
      char ch = configFile.read();
      if (ch == DELIMITER) {
        endmsg_CFG = true;
        message_CFG.toCharArray (Message, BUFFERLENGTH - 1);
        message_CFG = "";
        goto endread;
      } else if (ch != '\r') message_CFG += char(ch);   // Store string from CONFIG file
    }
    loadConfiguration = false;
    configFile.close();
    endmsg_CFG = true;
    message_CFG.toCharArray (Message, BUFFERLENGTH - 1);
    message_CFG = "";
    goto endread;
  }

  while (Serial.available()) {
    char ch = Serial.read();
    if (ch == DELIMITER) {
      endmsg_COM = true;
      message_COM.toCharArray (Message, BUFFERLENGTH - 1);
      message_COM = "";
      goto endread;
    } else if (ch != '\r') message_COM += char(ch);     // Store string from serial command
  }

  while (Serial1.available()) {
    char ch = Serial1.read();
    if (ch == DELIMITER) {
      endmsg_BT = true;
      message_BT.toCharArray (Message, BUFFERLENGTH - 1);
      message_BT = "";
      goto endread;
    } else if (ch != '\r') message_BT += char(ch);      // Store string from bluetooth command
  }
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

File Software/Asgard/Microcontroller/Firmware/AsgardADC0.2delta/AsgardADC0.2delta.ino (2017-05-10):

/* Work in progress Asgard ADC Firmware Relase 0.2 delta 09/05/2017 Nighttime
   This is a preliminary release, work in progress. Misbehaviour is plausible.
   AsgardADC0.2delta.ino - Air Data Computer Firmware
   Firmware for Teensy 3.6 MCU
  -> Prior to compile please change buffer to 1024 Byte TX/RX_BUFFER_SIZE. For coherence set also  RTS_HIGH_WATERMARK (SERIAL1_RX_BUFFER_SIZE-512),RTS_LOW_WATERMARK  (SERIAL1_RX_BUFFER_SIZE-600). IRQ not modified.
  -> \Arduino\hardware\teensy\avr\cores\teensy3\serial1.c
   Created by JLJ and G.C.
   BasicAirData Team.

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
   You should have received a copy of the GNU General Public License
   along with this program. If not, see <http://www.gnu.org/licenses/>.
*/
#include <AirDC.h>
#include <CapCom.h>
#include <SD.h>
#include <SPI.h>
#include <SD_t3.h>
#include <i2c_t3.h> //Library for second I2C 
#include <SSC.h>  //Library for SSC series sensors, support two bus I2C
//#define DELIMITER '\n'      // Message delimiter. It must match with Android class one;
const int chipSelect = BUILTIN_SDCARD; //HW pin for micro SD adaptor CS
AirDC AirDataComputer(1);
AirDC *ptrAirDC = &AirDataComputer;
CapCom CC(1);
int InitTime = 0; //To handle first time opened SD card

int TsensorPin = A0;       // select the input pin for the Temperature sensor
double temperature = 0.0;
double dp = 0.0;
double pstatic = 0.0;
SSC diffp(0x28, 0);
SSC absp(0x28, 1);//  create an SSC sensor with I2C address 0x28 on I2C bus 1
boolean sd_present = false;
//Accessory variables for Air Data calculations
double iTAS, ip1TAS, res, iof;
//Communication related vars
bool endmsg = false;
char input[INPUT_SIZE + 1];
char outputb[OUTPUT_SIZE + 1];
char *ch;
// Create an IntervalTimer object for acquisition time base
IntervalTimer TimeBaseDefault;
//IntervalTimer TimeBase;
int AcqTime = 5000000; //Default time interval between two #10 recurrent messages
//int AcqTime = 0; //Default time interval between two #10 recurrent messages
unsigned char bytecount = 0;
void setup()
{
  //Deafult configuration for ADC Hardware. 1 present; 0 not installed
  AirDataComputer._status[0] = '0'; //SD Card
  AirDataComputer._status[1] = '1'; //Deltap pressure sensor
  AirDataComputer._status[2] = '1'; //Absolute pressure sensor
  AirDataComputer._status[3] = '1'; //External temperature sensor
  AirDataComputer._status[4] = '1'; //Deltap sensor temperature
  AirDataComputer._status[5] = '1'; //Absolute pressure sensor temperature
  AirDataComputer._status[6] = '0'; //Real time clock temperature temperature
  AirDataComputer._status[7] = '0'; //Error/Warning
  AirDataComputer._status[8] = '1'; //BT Module present on serial1
  InitTime = 1; //First run
  pinMode(TsensorPin, INPUT);                       // and set pins to input.

  if (AirDataComputer._status[8] == '1') { // Serial monitor at 9600 bps over BT module
    Serial1.begin(9600);
  }
  else {
    Serial.begin(115200);// Begin the serial monitor at 115200 bps over the USB
  }
  Wire.begin(); // I2C Bus 0
  Wire1.begin(); //I2C Bus 1
  //Setup sensors parameters
  diffp.setMinRaw(1638.3);
  diffp.setMaxRaw(14744.7);
  diffp.setMinPressure(-6984.760);
  diffp.setMaxPressure(6984.760);
  absp.setMinRaw(1638.3);
  absp.setMaxRaw(14744.7);
  absp.setMinPressure(0.0);
  absp.setMaxPressure(160000.0);
  //Init SDCard
  if (AirDataComputer._status[0] == '1') {
    Serial.print("Initializing SD card...");
    if (!SD.begin(chipSelect)) {
      Serial.println("initialization failed!");
      return;
    }
    Serial.println("initialization done.");
  }
  //Recursive transmission interval
  TimeBaseDefault.begin(sendout, AcqTime); //Hook an interrupt to sendout routine with defaul interval value
  CC._ReqPeriod = AcqTime;
  InitTime = 1; //First run
}
void loop()
{
  delay(500);
  noInterrupts();
  comm();
  acquisition();
  computation();
  interrupts();

}
void sendout() {
  noInterrupts();
  //Periodically send out data
  //Send out periodic data
  CC.DTA(ptrAirDC, outputb);
  if (AirDataComputer._status[8] == '1') { //Output string sent through Bluetooth
    Serial1.println(outputb); //Send out formatted data
  } else
  {
    Serial.println(outputb); //Send out formatted data to USB
  }
  if (AirDataComputer._status[0] == '1')
  { //Saves to SD Card
    //Write Header
    File dataFile = SD.open("datalog.csv", FILE_WRITE);
    // if the file is available, write to it:
    if (dataFile) {
      dataFile.println(outputb);
      dataFile.close();
    }
    // pop up an error
    else {
      //  Serial.println("error opening datalog.csv");
    }
  }
  interrupts();
}
void computation() {
  // put your main code here, to run repeatedly:
  AirDataComputer._p = pstatic;
  AirDataComputer._qc = dp;
  AirDataComputer._RH = 0; //No sensor for RH, we are selecting dry air but the library will handle moist air if required
  AirDataComputer._TAT = temperature + 273.15; //Total Air Temperature
  //Computation
  //Init
  AirDataComputer._T = temperature + 273.15;
  AirDataComputer.RhoAir(1);// Calculates the air density
  AirDataComputer.Viscosity(2);// Calculates the dynamic viscosity, Algorithm 2 (UOM Pas1e-6)
  AirDataComputer.CalibrationFactor(1); //Calibration factor set to 1
  AirDataComputer.IAS(1); //Calculates IAS method 1
  AirDataComputer._TAS = AirDataComputer._IAS;
  AirDataComputer.Mach(1); //Calculates Mach No
  AirDataComputer.OAT(1); //Outside Air Temperature
  //Wild iteration
  iof = 1;
  while ((res > 0.05) || (iof < 10)) {
    AirDataComputer.RhoAir(1);// Calculates the air density
    AirDataComputer.Viscosity(2);// Calculates the dynamic viscosity, Algorithm 2 (UOM Pas1e-6)
    AirDataComputer.CalibrationFactor(2); //Update calibration fator vat at TAS
    AirDataComputer.IAS(1); //IAS
    AirDataComputer.CAS(1); //CAS
    AirDataComputer.TAS(1); //True Air Speed
    AirDataComputer.Mach(1); //Update Mach No
    iTAS = AirDataComputer._TAS; //Store TAS value
    AirDataComputer.OAT(1); //Update outside Air Temperature
    AirDataComputer.RhoAir(1);// Calculates the air density
    AirDataComputer.Viscosity(2);// Calculates the dynamic viscosity, Algorithm 2 (UOM Pas1e-6)
    AirDataComputer.CalibrationFactor(2); //Update calibration fator vat at TAS
    AirDataComputer.TAS(1); //Update TAS
    AirDataComputer.Mach(1); //Update Mach No
    AirDataComputer.OAT(1); //Update outside Air Temperature
    ip1TAS = AirDataComputer._TAS;
    res = abs(ip1TAS - iTAS) / iTAS;
    iof++;
  }
  //Uncorrected ISA Altitude _h
  AirDataComputer.ISAAltitude(1);
  AirDataComputer._d = 8e-3;
  AirDataComputer.Red(1);
}
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

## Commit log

2015-12-04 ADC Library
    ADC General Purpose Library
2015-12-06 Added Pressure Sensor
    Included Pressure Sensor HCLA12
2016-01-04 Secure Digital Card support added, Temperature Datalog skeleton tested, check examples
2016-01-07 Working Example for SD Enabled Temperature and BaD logger
2016-01-07 Fixed frozen boot when Teensy powered by battery
2016-01-09 Teensy TODO and HISTORY
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2016-08-05 Added base sketch for ADC HW test
2017-01-04 Added: ADC Common Message Set.odt
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2017-03-12 Added Acquire Sensors Data.xml
2017-03-12 Added Acquire Sensors Data.jpg
2017-03-12 Update Acquire Sensors Data.xml
2017-03-13 Added Use Case Configuration.jpg
2017-03-13 Added Use Case Configuration.xml
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2017-03-25 Up 3D Teensy 3.6
    [24 Pin Straight Header.0004.iam, 24 Pin Straight Header.iam, 5031821852MICROSDADAPTER.0005.ipt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]
2017-03-27 template Kicad
    [BAD.sch]
2017-03-27 Update initial file for Kicad with template
    [PCB.kicad_pcb, PCB.sch]
2017-03-27 Updated Template Kicad
    [PCB.sch]
2017-03-27 Initial setup of Kicad
    Libraries setup
    [Asgard.sch]
2017-03-28 Proposal Asgard Schematics
    Ready for routing
    [Asgard.kicad_pcb, Asgard.sch]
2017-03-28 PCB Preliminary Layout
    [Asgard.kicad_pcb, Asgard.sch]
2017-03-28 PCB-Init Commit
    [Asgard.kicad_pcb]
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2017-03-31 STEP Teensyv3.6
    [5031821852MICROSDADAPTER.ipt, Teensy3.6withheaders.stp]
2017-04-16 Added Temperature sensor Test01
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2017-04-17 Changed A9 to A0 for the Temperature sensor
2017-04-18 HW test sketch for Asgard ADC
2017-04-18 secret is the wash
    [Asgard.sch]
2017-04-19 ADC Algorithm
    Starting to pull together the code
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2017-04-26 Work in progress with interrupt timing online
2017-04-28 Sorting
    Sorting
    Serial Test Session
    Grouped Teensy Libraries
2017-04-29 Removed double '\n?
    \n is now appended only in the main sketch by the .println command.
2017-05-07 Attach BroadcastReceiver on Create
2017-05-08 Update the terminal in UI Thread
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2017-05-22 Updated Schematics
    Addedd indication for HC-05/HC-06 Compatibility
    [Asgard.kicad_pcb, Asgard.sch]
2017-05-22 Fiddling with packages
    [Asgard.kicad_pcb, Asgard.sch]
2017-05-22 Added doc
    Schematics pdf
    New PCB laysout started
    [Asgard.kicad_pcb, PCBLayout.dxf]
2017-05-23 Schematics update
    GPIO connector is hard to place
    [Asgard.kicad_pcb, Asgard.sch]
2017-05-23 PCB Rel 1
    First Release of PCB
    [Asgard.kicad_pcb, Asgard.sch]
2017-05-24 PCB proposal
    [Asgard.kicad_pcb, Asgard.sch]
2017-05-24 PCB Candidate
    Vertical mounted resistors
    [Asgard.kicad_pcb]
2017-05-24 PCB Candidate 2
    [Asgard.kicad_pcb, Asgard.sch]
2017-05-24 PCB Candidate 3
    [Asgard.kicad_pcb]
2017-05-24 PCB candidate 4
    [Asgard.kicad_pcb, Asgard.sch]
2017-05-25 PCB Candidate 5
    Added labels on silkboard
    [Asgard.kicad_pcb]
2017-05-25 PCB Candidate 6
    [Asgard.kicad_pcb]
2017-05-25 Holes updated
    [Asgard.kicad_pcb]
2017-05-25 Corrected rounded sizes
    [Asgard.kicad_pcb]
2017-05-26 Updated Holes
    [Asgard.kicad_pcb]
2017-05-28 Moved holes in PCB
    [Asgard.kicad_pcb]
2017-05-28 Pressure sensors inverted
    [Asgard.kicad_pcb, Asgard.sch]
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2017-05-30 Polishing the board
    [Asgard.kicad_pcb]
2017-05-30 Getting files ready for PCB
    [Asgard.kicad_pcb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]
2017-06-03 3D Print files
    STL Files for 3D print of Asgard Enclosure
2017-10-25 BOM Kicad
    [Asgard.csv, Asgardr1.csv]
2017-10-25 BOM 2
    [BOM for PCB only ASGARD.xlsx]
2017-10-26 WIN PCB files
    [Asgard-B.Cu.gbl, Asgard-B.Mask.gbr, Asgard-B.SilkS.gbo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]
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2018-01-08 Added current release folder
    The number of ADC release is now standardized and equal to 0.0.0
2018-01-09 Rup Scprit
    Init Scilab Scripts
    [201 - Case Front i2.stl, 203 - Case Back i2.stl, 50-25.CSV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]
2018-01-09 Fix the interval of first sample
    [AsgardADC.ino]
2018-01-10 Reversed qc
    qc was not of the right sign. Following the assembly intructions the
    resulting qc sign should be correct
2018-01-12 Scialb function to calculate moist air heat ratio added
    Scialb function to calculate moist air heat ratio added
2018-01-14 fix the SD init when mounted
    [AsgardADC.ino]
2018-01-15 Added msg 19 e 20 for #62 . Added cpcv calculation script
    Added msg 19 e 20 for #62 . Added cpcv Scilab calculation script
    [50-25.CSV, 50-50.CSV, DATALOG.CSV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]
2018-01-16 Added GPS Logger track support to SCilab script
    Added GPS Logger track support to SCilab script
    [PIPPO01GPS.CSV, PIPPO02GPS - Copia.CSV, PIPPO02GPS.CSV]
2018-01-16 Fix a possible loss of message when 2 messages are queued in the buffer
    [AsgardADC.ino]
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2018-01-17 Added Figure to Scilab Scripts
    Added Figure to Scilab Scripts
    [PIPPO02GPS - Copia.CSV]
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2018-01-17 Closed #73
    if selected into Scilab file (writetoQGISfile=1) a QGIS usable file is
    produced from ADC + GPS Data
    [FORQGIS.csv]
2018-01-22 Completed Msg No.19 and No.20
    Completed Msg No.19 and No.20. No 19 message command EXE Mode 2
    implementation will be completed in a second stage
2018-01-22 Complete No.19 and No.,20 #1
    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
2018-01-23 Allow to delete the current active file if ADC is not recording
2018-01-30 Added Hardware paramters for sensors
    Added Hardware paramters for sensors
2018-05-30 Script and data update
    [TEST1GPSR.csv, TEST1R.CSV]
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2019-01-21 playing with kicad
    Kicad draft
    [ADSSBb0.1.kicad_pcb, ADSSBb0.1.sch]
2019-01-22 Kicad experiments
    Kicad experiments
    [ADSSBb0.1.sch]
2019-01-23 Kicad +
    Kicad +
    [ADSSBb0.1.kicad_pcb, ADSSBb0.1.sch]

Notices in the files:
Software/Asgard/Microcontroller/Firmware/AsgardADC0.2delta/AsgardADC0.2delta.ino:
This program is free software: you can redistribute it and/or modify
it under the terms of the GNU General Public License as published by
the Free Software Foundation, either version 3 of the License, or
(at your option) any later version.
